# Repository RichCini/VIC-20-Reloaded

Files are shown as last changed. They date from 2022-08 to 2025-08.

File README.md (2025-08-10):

# VIC-20-Reloaded
Reimaging of the original VIC-20cr ("cost-reduced") main board in a smaller footprint based
on schmetics of the 251027-01D version as redrawn by Steve Gray. This should represent
changes through ECO 830151 as of 4/12/1983.

## Introduction
This project is a re-implementation of a VIC-20 based on the cost-reduced version from 1983.
It's built using commonly-existing TTL (all of the original types of chips used are still 
generally available) and original core chips from a VIC-20 (the CPU, VIAs, VIC, and original
mask ROMs) which were typically socketed. The memory chips (2114L and 6116), which are not
typically socketed, are still available as used or new-old-stock. 

## How is this version similar?
Since it's based on the original schematics, it's identical operationally and 99% identical
electrically (except as noted in the next section). I also tried to keep the parts placement
relationally similar to the original, recognizing that the board size is different. Parts 
designators are the same.

## How is this version different?
### Size
My main goal was to reimplement the VIC in a smaller form factor. I was able to squeeze it
{mostly} into an S-100 format (which is 10" x 5"; actual is 10.375" x 5.375") size. As such,
this board isn't a drop-in replacement. However, the spacing and placement of the side 
(power/joystick) and the rear (expansion cartridge, video, serial IEC) are
placed at the correct distances from the upper-right corner.

### Ports
Due to the smaller form factor, the cassette port was eliminated (instead opting for a 
6-pin header for an external driver) and the user port was moved to the left side. The 
orientation of the expansion connector was changed to vertical (more like the Atari 2600
which saved about 2" of board space). Using the expansion connector is limited to one
cartridge, or an expansion board that uses two pieces connected by a cable (there is
another repro here that has an example).

### Power
Electrically, I opted for a single 5V power supply (9VAC wasn't needed as there is no
cassette port), and the power switch is slightly different due to parts availability.
The main fuse holder is different, but the same 5x20mm fuse is used. Large axial
capacitor was replaced with smaller radial cap of the same value.

### Other
Since the board is autorouted to a smaller footprint, circuit paths and keepout
areas are different from the original.

## Versions
* v1.0-001: Initial prototype based on original schematic; screen artifacts
* v1.1-001: Second prototype with a rearranged chip layout; screen artifacts.
* v1.1-002: Third prototype. A transcription error was found in the original schematic.  
            Corrected. Works.
* v1.1-002E: Final version.

## Known Bugs
Current Release (1.1-002E):
* The signal flag "S01" was incorrectly used for the CPU PHI1 output. The system works
  with this improperly connected signal, but the fix is to lift pins UE10.3 and UC3.3
  and connect them with a jumper. The way the traces are routed make it hard to make a
  single-cut fix.

Prior Release (1.1-002D): 
* An error was introduced in this version as a result of rearranging the data bus lines
  lines on IC UF8 (74LS245). D4 (pin 4) and D5 (pin 5) were reversed. There is a picture
  (ECO_001) which indicates a convenient place to cut two traces and cross-wire them.
  Will be fixed in the next version.

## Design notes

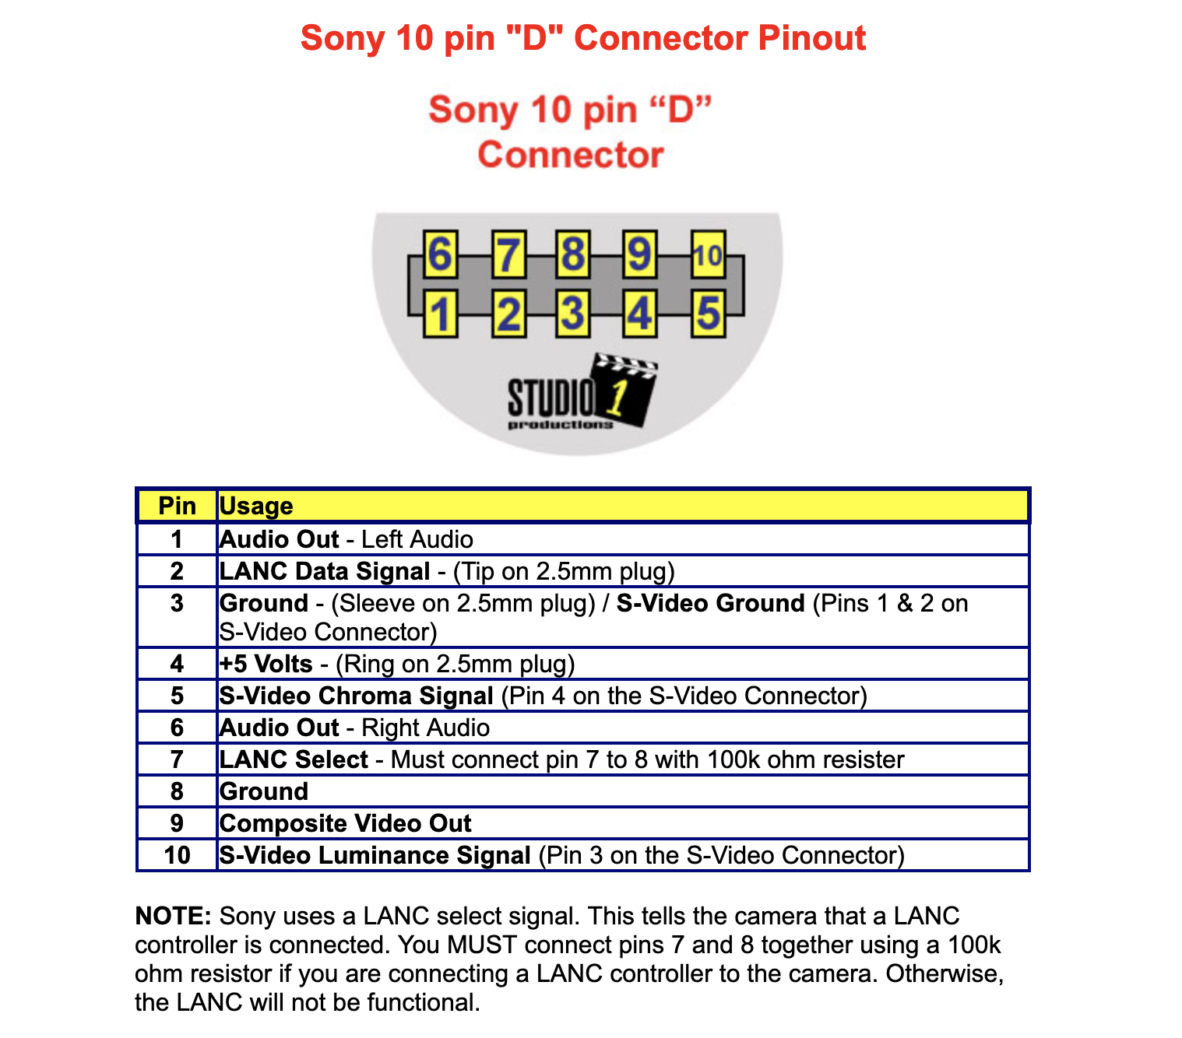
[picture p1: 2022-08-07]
sony_svideo_cable.png

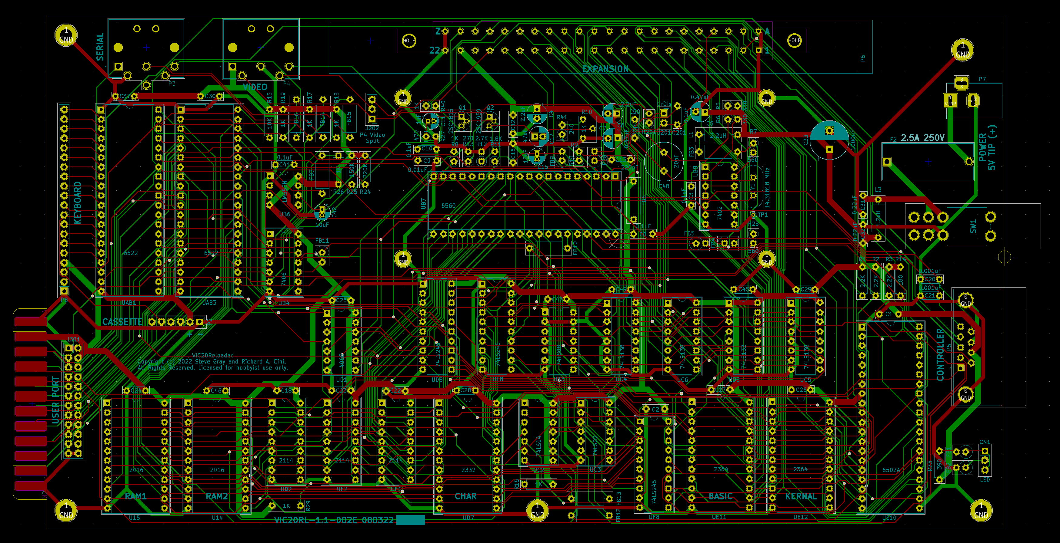
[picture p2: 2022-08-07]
Screen Shot 2022-08-06 at 4.35.58 PM.png

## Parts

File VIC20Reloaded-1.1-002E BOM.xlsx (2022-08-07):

Item | Qty | Order | Reference(s) | Value | Description | Footprint | Mouser Part Number
1 | 24 |  | C1, C2, C3, C8, C10, C12, C16, C18, C22, C23, C24, C25, C26, C27, C28, C29, C30, C37, C41, C45, C46, C47, C49, C201 | 0.1uF 50v X7R | Bypass capacitor 5mm | Capacitor_THT:C_Disc_D4.3mm_W1.9mm_P5.00mm | K104K15X7RF53H5
2 | 2 |  | C4, C6 | 2.2uF 35v | Tantalum | Capacitor_THT:CP_Radial_D5.0mm_P2.50mm | 581-TAP225M035SCS
3 | 2 |  | C5, C7 | 0.47uF 35v | Tantalum | Capacitor_THT:CP_Radial_D5.0mm_P2.50mm | 581-TAP474K035SCS
4 | 1 |  | C9 | 0.01uF | MLCC | Capacitor_THT:C_Disc_D4.3mm_W1.9mm_P5.00mm
5 | 1 |  | C11 | 1uF 50v | Electrolytic 4x1.5mm | Capacitor_THT:CP_Radial_D4.0mm_P1.50mm | UMA1H010MDD
6 | 1 |  | C13 | 220pF 50v | MLCC | Capacitor_THT:C_Disc_D4.3mm_W1.9mm_P5.00mm | FG28C0G1H221JNT06
7 | 2 |  | C15, C42 | 10uF 50v | Electrolytic 4x1.5mm | Capacitor_THT:CP_Radial_D4.0mm_P1.50mm | 50ML10MEFC5X7
8 | 1 |  | C17 | 47uF 25v | Electrolytic 4x2mm | Capacitor_THT:CP_Radial_D4.0mm_P2.00mm | ESS476M016AC2AA
9 | 2 |  | C20, C21 | 0.001uF 50v | MLCC | Capacitor_THT:C_Disc_D4.3mm_W1.9mm_P5.00mm
10 | 2 |  | C31, C32 | 0.22uF 50v | MLCC | Capacitor_THT:C_Disc_D4.3mm_W1.9mm_P5.00mm | 810-FG24X7R1H224KNT00
11 | 1 |  | C33 | 2200uF, 16v Alt | Electrolytic 10x16x5mm | Capacitor_THT:CP_Radial_D10.0mm_P5.00mm | 80-A750MW228M1CAAE10
12 | 1 |  | C48 | 20pF 100v | trimmer cap (red) 6-30pF | Capacitor_THT:C_Radial_D10.0mm_H12.5mm_P5.00mm | GKG30015
13 | 1 |  | C50 | 15pF 50v | ceramic | Capacitor_THT:C_Disc_D4.3mm_W1.9mm_P5.00mm | FG28C0G1H150JNT06
14 | 1 |  | CN1 | CONN_01X03 | 1x3 0.1" header/power LED | Connector_PinHeader_2.54mm:PinHeader_1x03_P2.54mm_Vertical
15 | 1 |  | F2 | 2.5A 5mm FB fuse |  | standard 5x20mm fuse | 530-5SF2.5-R
16 | 1 |  | F2X | 5mm fuse holder |  | Fuse holder, Keystone 4527 | 534-4527
17 | 1 |  | F2X1 | fuse holder cover |  | Fuse holder, Keystone 4527 cover | 534-4527C
18 | 7 |  | FB1, FB2, FB4, FB5, FB8, FB9, FB11 | FILTER | ferrite bead, Fair-Rite | Inductor_THT:L_Axial_L7.0mm_D3.3mm_P2.54mm_Vertical | 2743001112
19 | 9 |  | FB3, FB6, FB7, FB10, FB12, FB13, FB14, FB15, FB16 | FILTER | ferrite bead, Fair-Rite | Inductor_THT:L_Axial_L7.0mm_D3.3mm_P10.16mm_Horizontal | 2743001112
20 | 1 |  | J201 | Jumper 1x3 |  | video configuration jumper
21 | 1 |  | J202 | Jumper 1x2 |  | video configuration jumper
22 | 1 |  | L1 | 2.2uH | inductor, Bourns, 630mA | Inductor_THT:L_Axial_L7.0mm_D3.3mm_P10.16mm_Horizontal | 78F2R2K-RC
23 | 1 |  | L3 | 1.2uH | inductor, TDK, 4.25A | Inductor_THT:L_Axial_L7.0mm_D3.3mm_P10.16mm_Horizontal | B82144F2122K000
24 | 1 |  | P1 | CONN_02X12 | 2x12 0.1" header USERP | Connector_PinHeader_2.54mm:PinHeader_2x12_P2.54mm_Vertical
25 | 1 |  | P2 | Header, 1x6 | 1x6 0.1" header CASS | Connector_PinHeader_2.54mm:PinHeader_1x06_P2.54mm_Vertical
26 | 1 |  | P3 | DIN6 | DIN6 Serial IEC |  | SDS-60J
27 | 1 |  | P4 | DIN5 | DIN5 Video |  | 490-SDS-50J
28 | 1 |  | P5 | DE9M | DE9M/joystick | Connector_Dsub:DSUB-9_Male_Horizontal_P2.77x2.84mm_EdgePinOffset7.70mm_Housed_MountingHolesOffset9.12mm | ID09P33E4GX00LF
29 | 1 |  | P6 | EXPANSION | 2x22 card connector | EDAC. Can be vertical or R/A depending on need | 307-044-524-202
30 | 1 |  | P6-Alt | EXPANSION | 2x22 R/A card connector | EDAC. Can be vertical or R/A depending on need | 307-044-558-201
31 | 1 |  | P7 | POWER TIP+ | barrel jack | Connector_BarrelJack:BarrelJack_Horizontal | PJ-002AH
32 | 1 |  | P8 | CONN_01X20 | 1x20 0.1" header KEYB | Connector_PinHeader_2.54mm:PinHeader_1x20_P2.54mm_Vertical
33 | 1 |  | Q1 | 2SC1815 | transistor | Can substitute 2N2222 | N/A
34 | 1 |  | Q2 | 2SC1959 | transistor | Can substitute 2N2222 | N/A
35 | 3 |  | R1, R2, R3 | 2.2KQ | resistor, 1/4w
36 | 2 |  | R5, R6 | 330Q | resistor, 1/4w
37 | 2 |  | R7, R28 | 560Q | resistor, 1/4w
38 | 1 |  | R9 | 510Q | resistor, 1/4w
39 | 1 |  | R10 | 1.0K vertical POT | trimmer, vertical Bourns 3266W |  | 652-3266W-1-102LF
40 | 1 |  | R11 | 1.8KQ | resistor, 1/4w
41 | 1 |  | R12 | 2.7KQ | resistor, 1/4w
42 | 1 |  | R13 | 270Q | resistor, 1/4w
43 | 1 |  | R14 | 180Q | resistor, 1/4w
44 | 6 |  | R15, R17, R18, R19, R26, R29 | 1.0KQ | resistor, 1/4w
45 | 2 |  | R8, R40 | 1.0KQ | resistor, 1/4w
46 | 1 |  | R16 | 10.0KQ | resistor, 1/4w
47 | 1 |  | R23 | 390Q | resistor, 1/4w | resistor for LED power indicator; may need to adjust based on LED
48 | 1 |  | R24 | 220KQ | resistor, 1/4w
49 | 1 |  | R25 | 150KQ | resistor, 1/4w
50 | 1 |  | R27 | 470Q | resistor, 1/4w
51 | 1 |  | R41 | 240Q | resistor, 1/4w
52 | 1 |  | R201 | 75Q | resistor, 1/4w | used for S-video modification
53 | 1 |  | SW1 | Switch, DPDT vertical | power | Mouser-Samec:M2022TXW41DA | 633-M2022TXW41-DA
54 | 1 |  | U13 | 74LS08 | Quad 2-in AND, OC |  | SN74LS08
55 | 2 |  | U14, U15 | 2016/6116 SRAM | RAM |  | N/A
56 | 2 |  | UAB1, UAB3 | R6522 VIA | VIA |  | N/A
57 | 1 |  | UB4 | 74LS06 | Hex inverter/buffer OC |  | SN74LS06
58 | 1 |  | UB6 | LM555N | timer |  | LM555CN
59 | 1 |  | UB7 | 6560 VIC-I | video |  | N/A
60 | 1 |  | UB9 | 7402 | Quad 2-in positive NOR |  | eBay-note it's original logic family
61 | 1 |  | UC2 | 74LS04 | Hex inverter |  | SN74LS04
62 | 1 |  | UC3 | 74LS02 | Quad 2-in positive NOR |  | SN74LS02
63 | 3 |  | UC4, UC5, UC6 | 74LS138 | 3-8 decoder/demux |  | SN74LS138
64 | 1 |  | UD1 | CD4066 | quad switch |  | CD4066BE
65 | 3 |  | UD2, UE1, UE2 | 2114AL-3 | 1kx4 SRAM |  | N/A
66 | 1 |  | UD7 | 2332 mask ROM | character ROM |  | N/A
67 | 3 |  | UD8, UE8, UF8 | 74LS245 | Octal bus transciever, tri-state |  | SN74LS245
68 | 1 |  | UD9 | 74LS133 | 13-input NAND |  | SN74LS133
69 | 1 |  | UE10 | 6502A | CPU |  | N/A
70 | 2 |  | UE11, UE12 | 2364 mask ROM | BASIC/KERNAL |  | N/A
71 | 1 |  | Y1 | 14.31818 MHz XTAL | must be series capacitance | Crystal:Crystal_HC49-U_Vertical | 774-MP143 | CTX088
72 | 1 |  |  | DIP8 | dual-wipe socket, crimp pin |  | 4808-3004-CP
73 | 6 |  |  | DIP14 | dual-wipe socket, crimp pin |  | 4814-3004-CP
74 | 4 |  |  | DIP16 | dual-wipe socket, crimp pin |  | 4816-3004-CP
75 | 3 |  |  | DIP18 | dual-wipe socket, crimp pin |  | 517-4818-3004-CP
76 | 3 |  |  | DIP20 | dual-wipe socket, crimp pin |  | 4820-3004-CP
77 | 5 |  |  | DIP24 | dual-wipe socket, crimp pin |  | 517-4824-6004-CP
78 | 4 |  |  | DIP40 | dual-wipe socket, crimp pin |  | 517-4840-6004-CP
 |  |  | P8F | 1x20 MTA100 | keyboard |  | 571-5-640440-0

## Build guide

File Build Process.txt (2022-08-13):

VIC20cr Reloaded Build Process
2022-08-13

In general, I build boards by component height rather than function. The former allows
for an easier bench build, while the latter enables testing by functional area of the
board. Each has its relative benefits which depend on the builder's confidence in 
building complex boards. I would note that some components are relatively expensive
(the expansion connector, the power switch, and the DE9M, for example) so I leave those
out until I confirm the board works.

Component-Oriented Build
========================
 1.	Axial components:
	Resistors: R1-3, R14-19, R23, R29
	Ferrites: FB3, FB6, FB10, FB12-16
	Inductors: L1
	
 2.	DIP Sockets. If the builder is using crimp-pin style sockets rather than the straight
	or machine pin, I recommend soldering them such that the iron rests on the knee
 	of the crimp and solder is applied in and around the vacant area under the pin
 	opposite where the iron is resting. That way, the solder fills the entire area.

 3.	Radial components:
	Capacitors: C8, C11, C13, C20-21, C31-32; all bypass caps, C48
	Inductors: L3

 4.	Axial (folded) components:
	Resistors: R5-8, R11-13, R27-28, R40-41
	Ferrites: FB1,2,4,5,8,9,11
	
 5.	Transistors

 6.	Other capacitors: C4,6,7,15,17,42

 7.	Crystal and ground wire

 8.	Headers P2, P8, CN1, J301

 9.	Capacitor C33

10.	Switch SW1

11.	Power jack P7

12. 	Fuse F7

13.	Joystick P5

14. 	Serial IEC/Video P3,P4

15.	Expansion Connector P6. Use two small 4-40 screws to secure to the board to 
	provide some strain relief.

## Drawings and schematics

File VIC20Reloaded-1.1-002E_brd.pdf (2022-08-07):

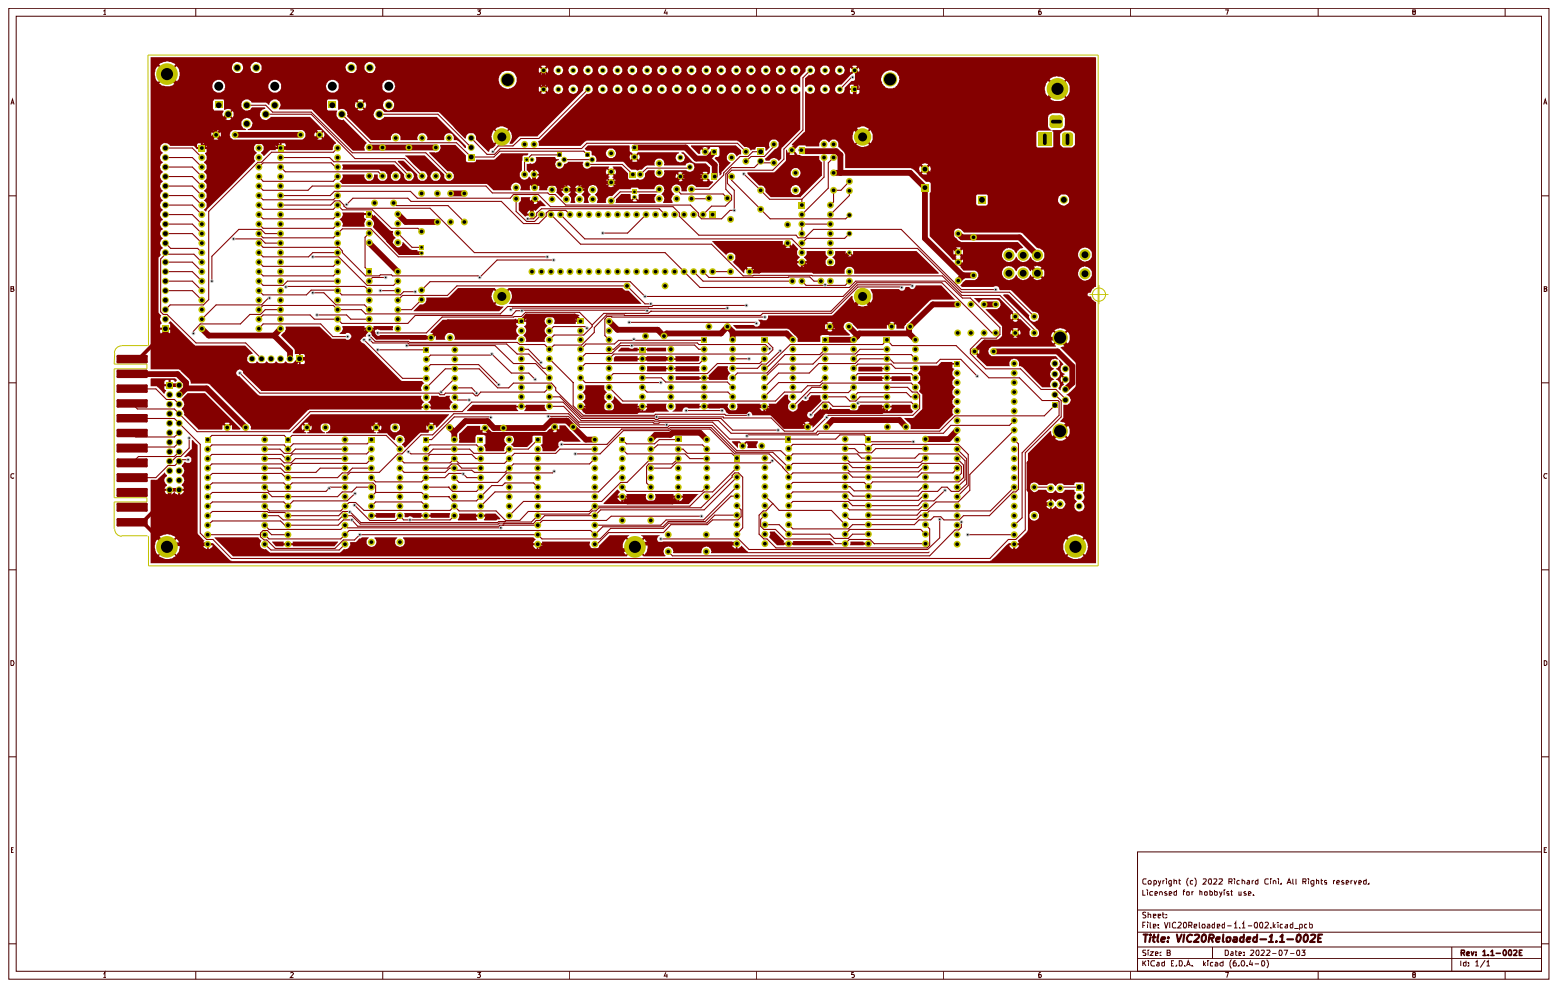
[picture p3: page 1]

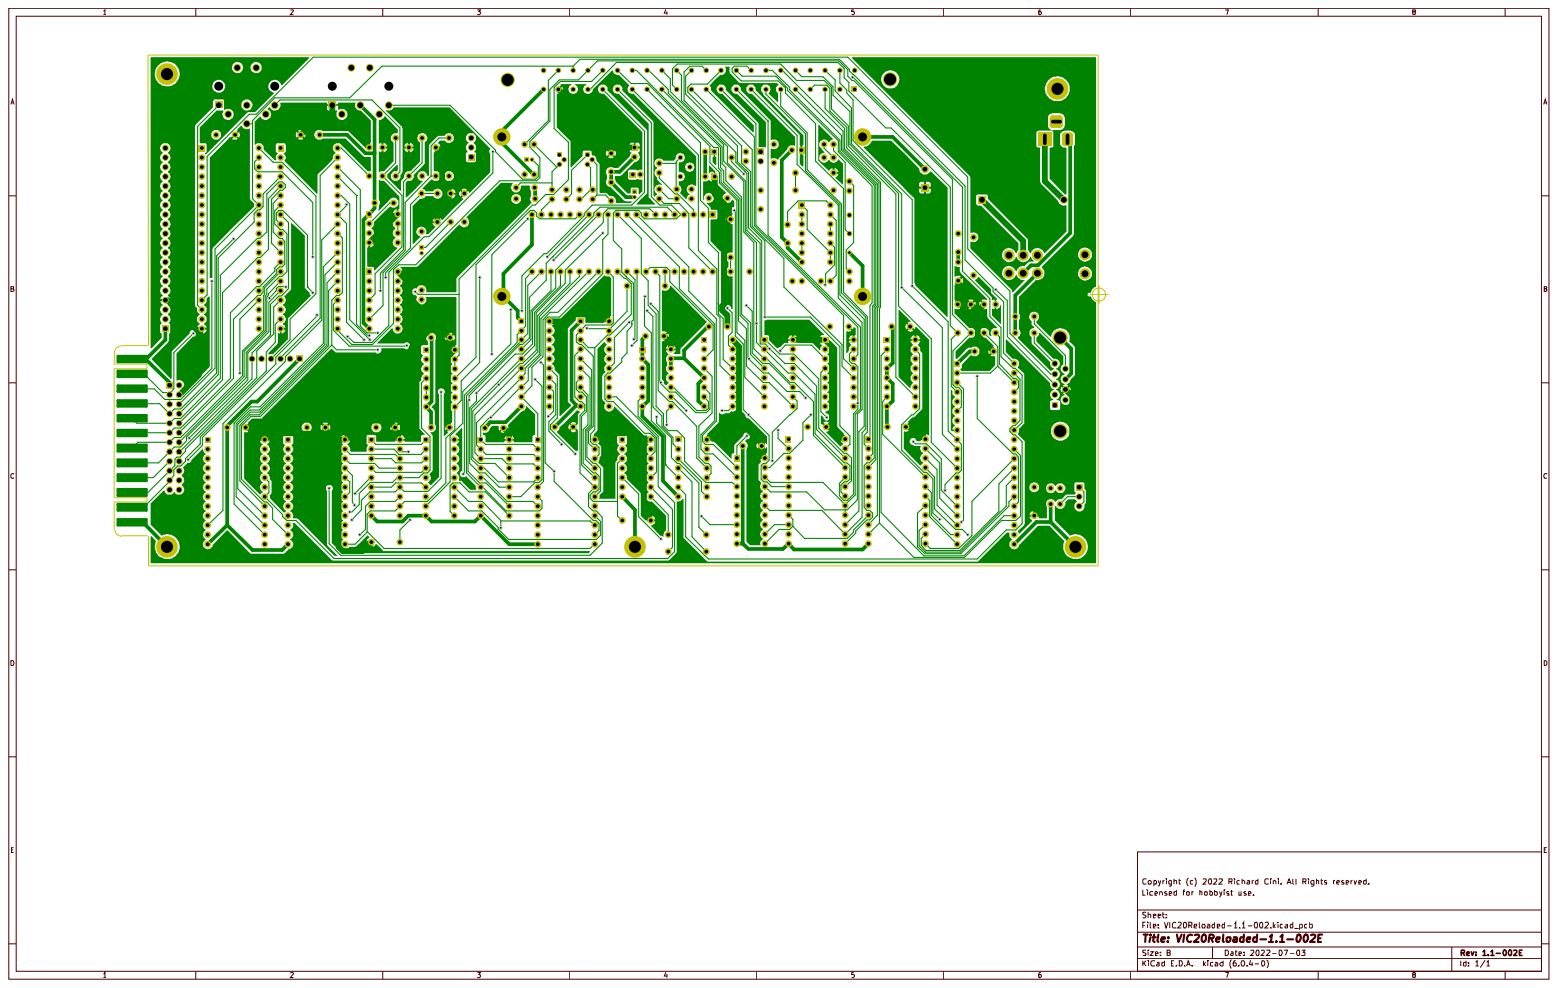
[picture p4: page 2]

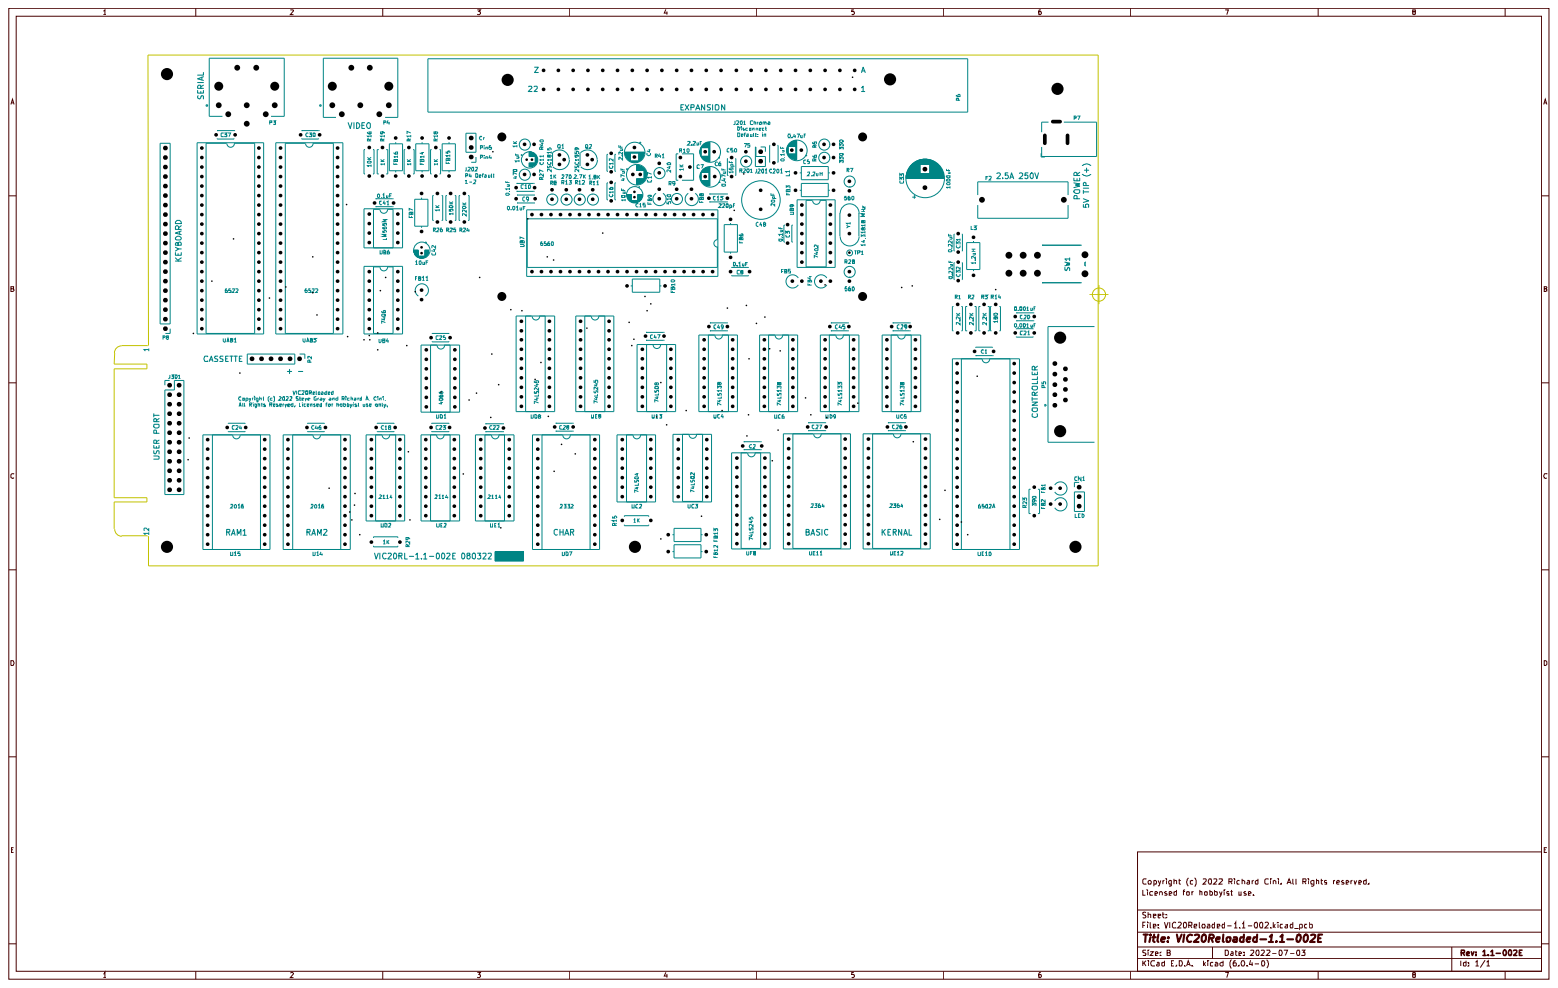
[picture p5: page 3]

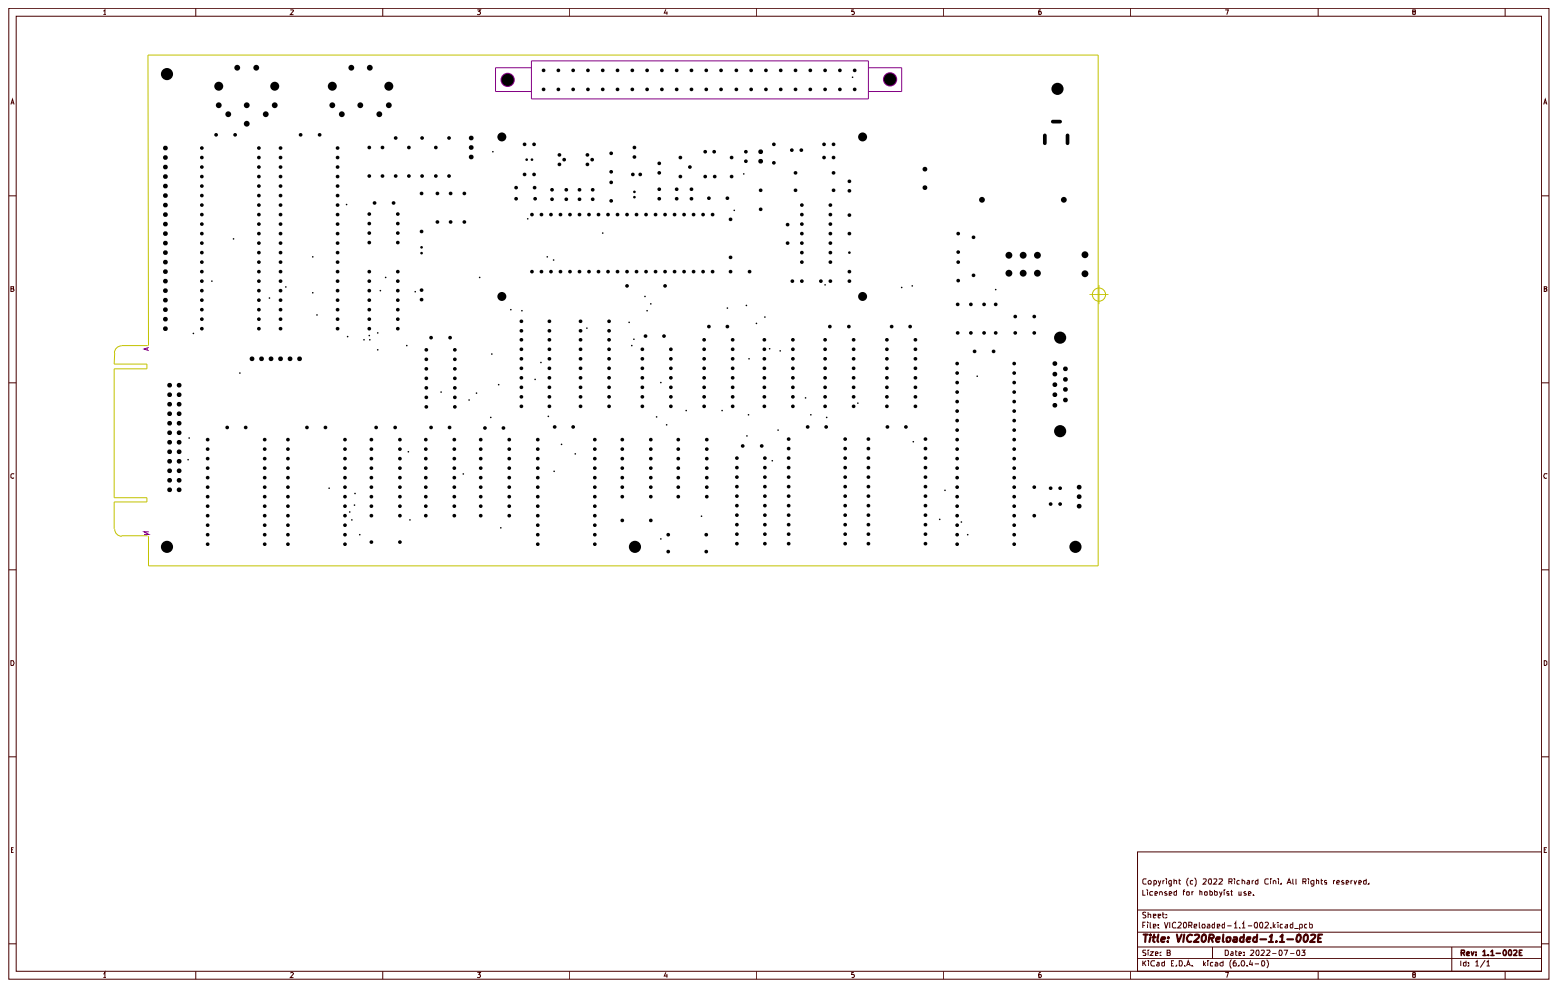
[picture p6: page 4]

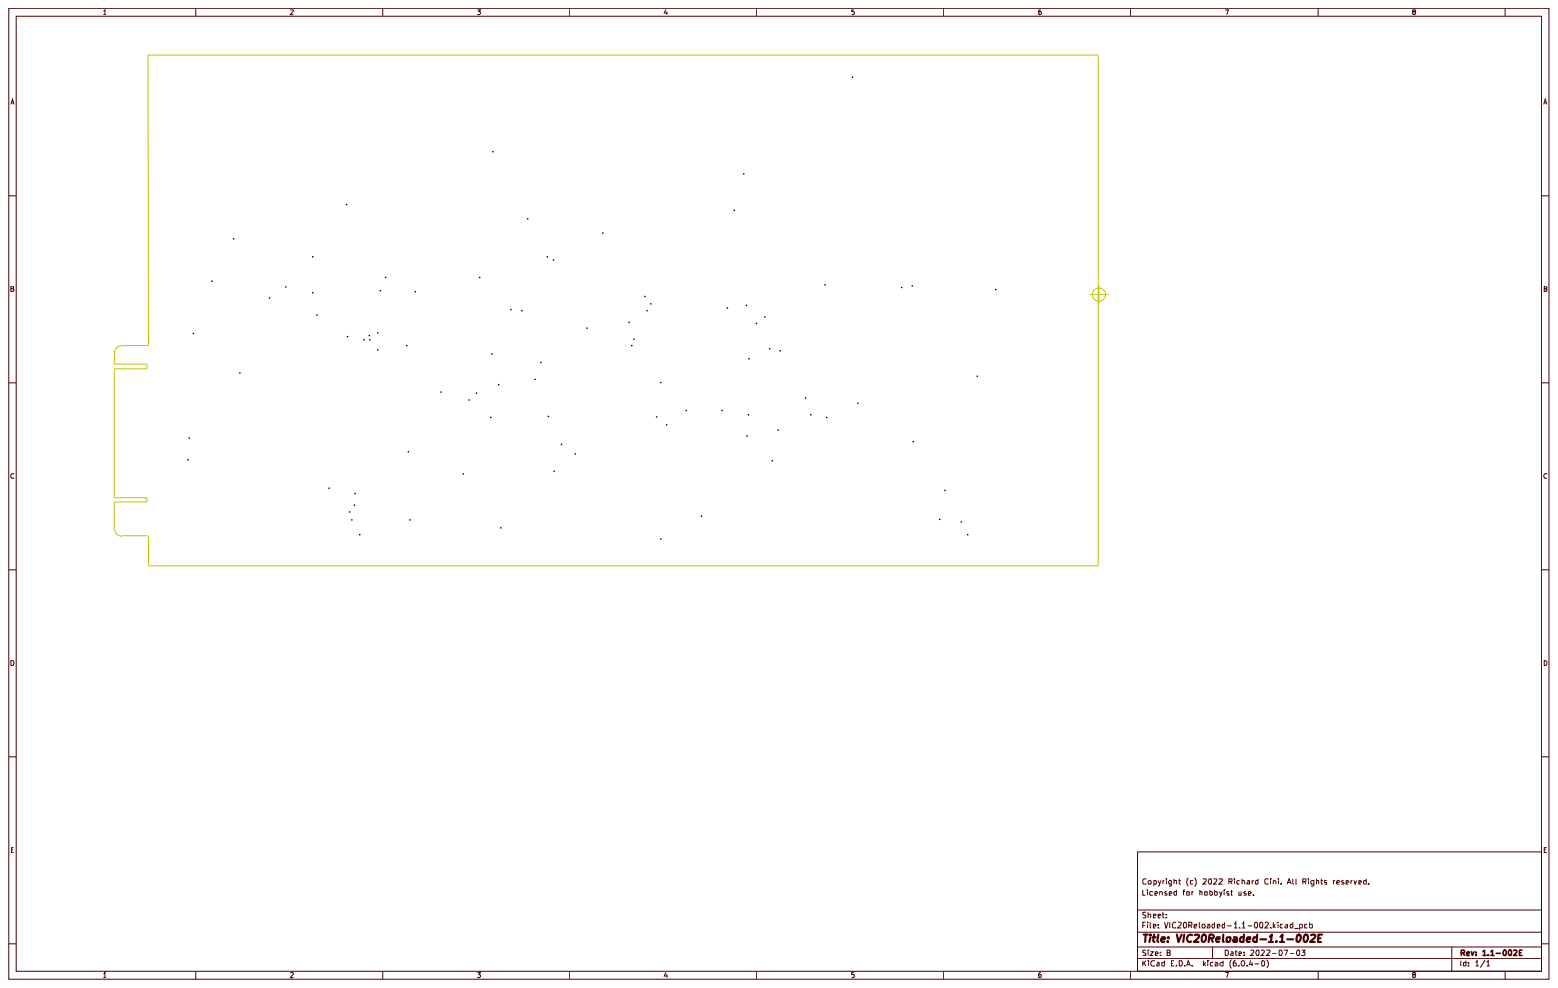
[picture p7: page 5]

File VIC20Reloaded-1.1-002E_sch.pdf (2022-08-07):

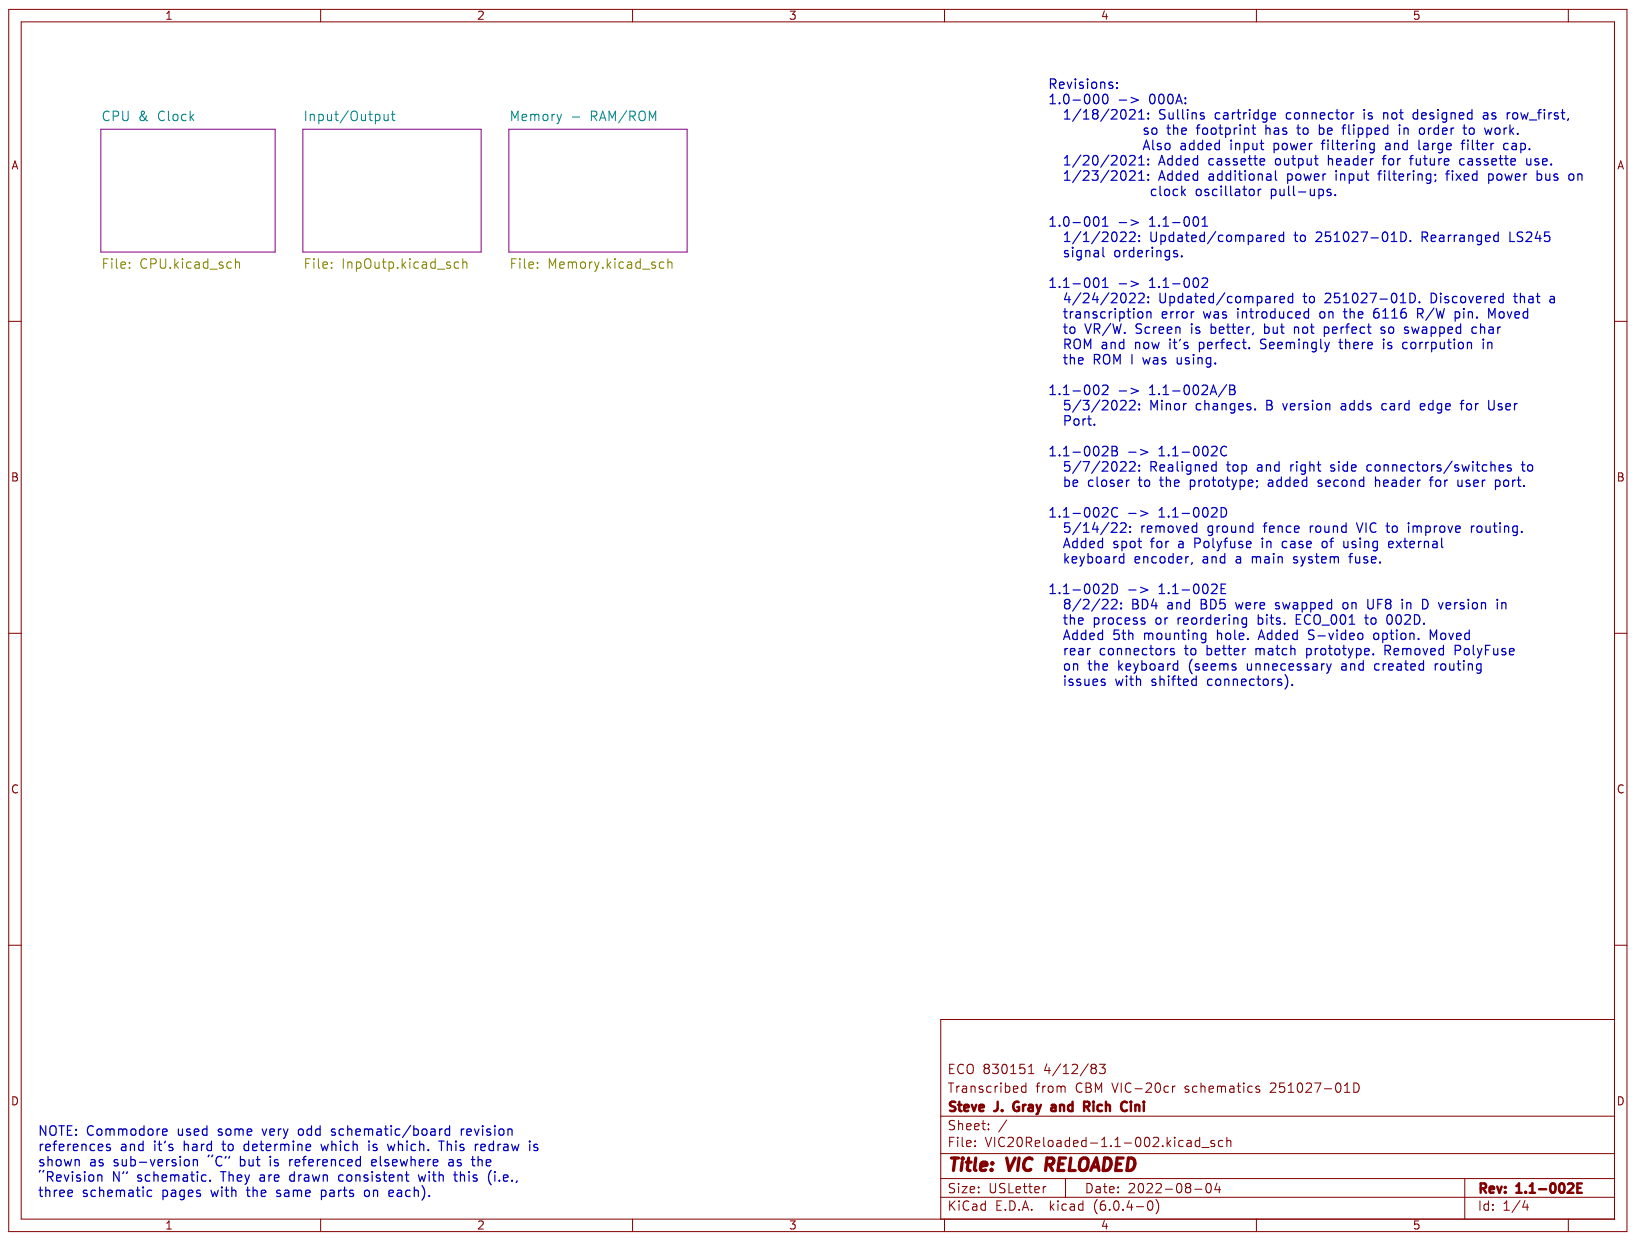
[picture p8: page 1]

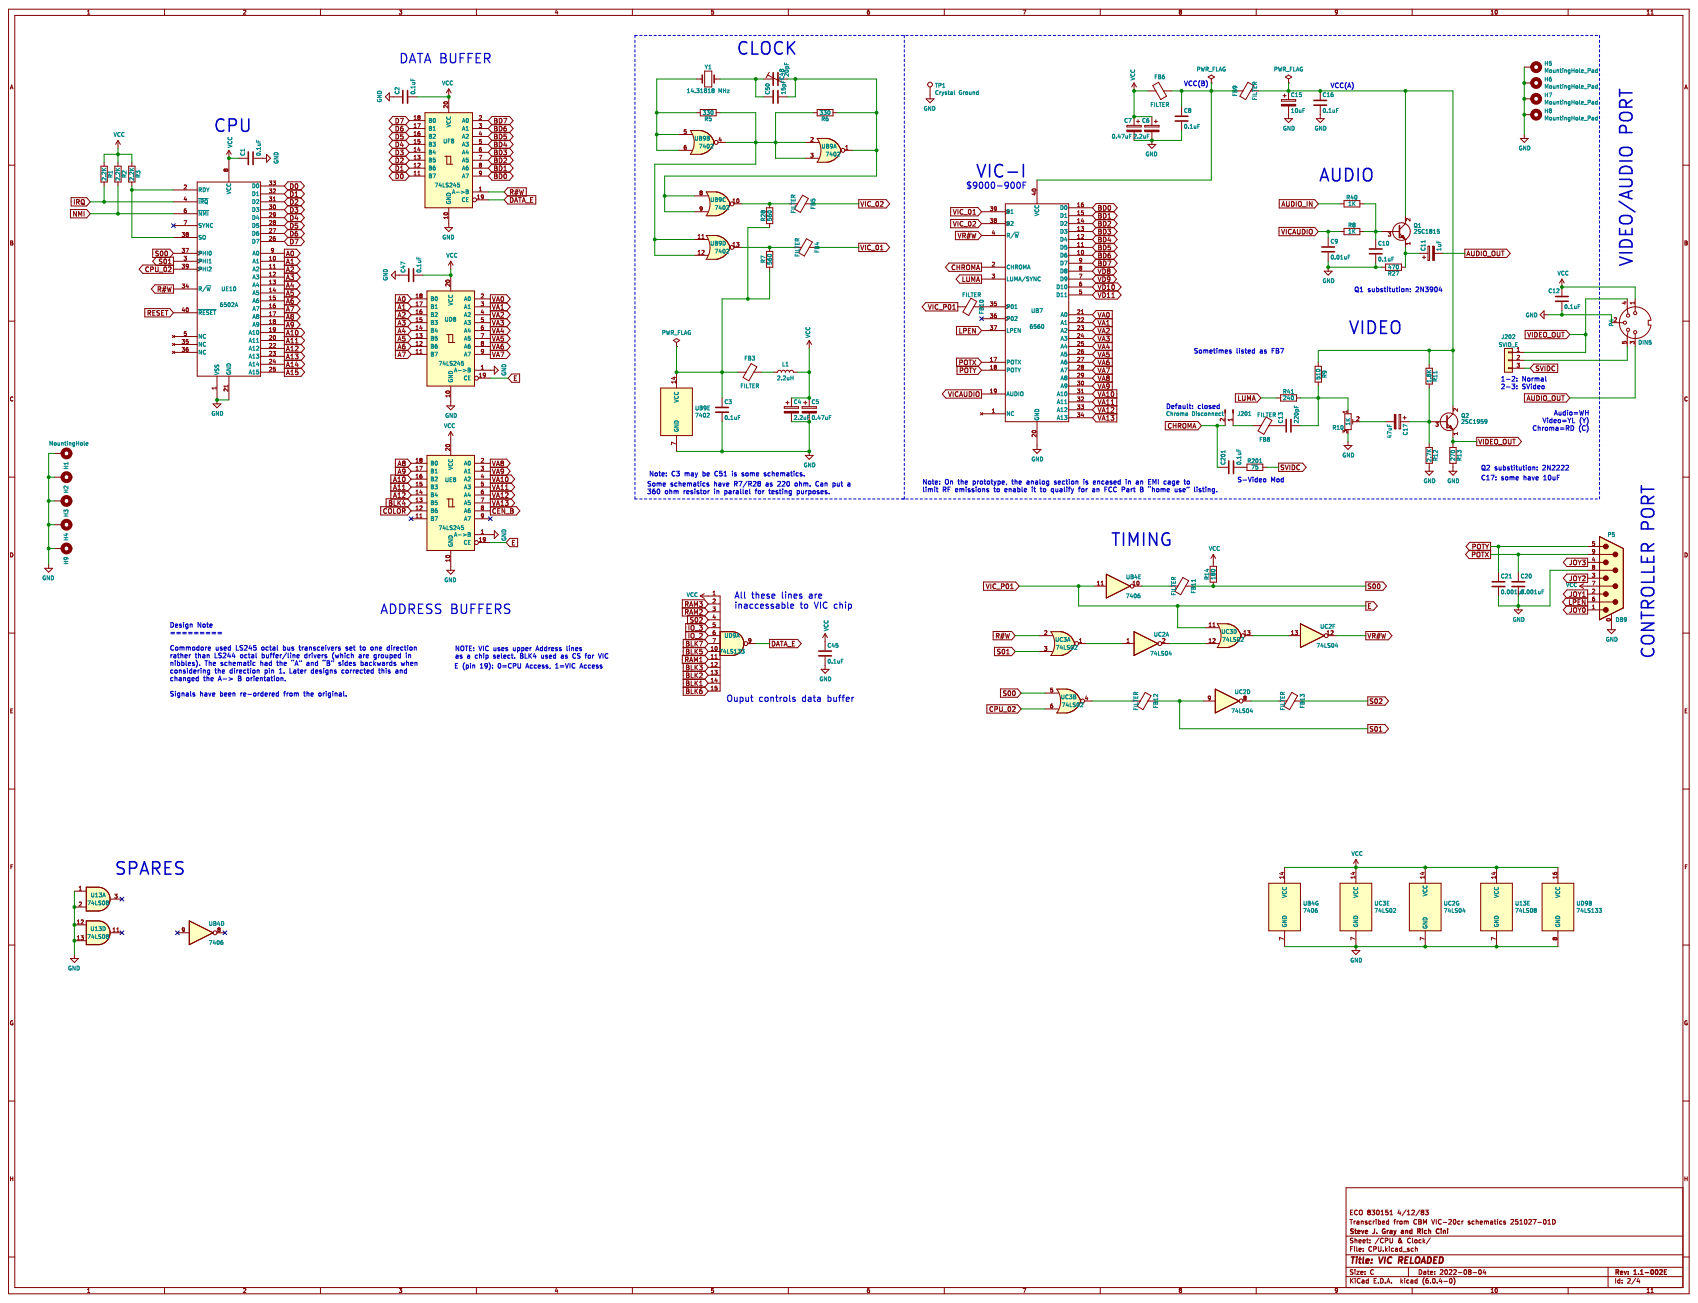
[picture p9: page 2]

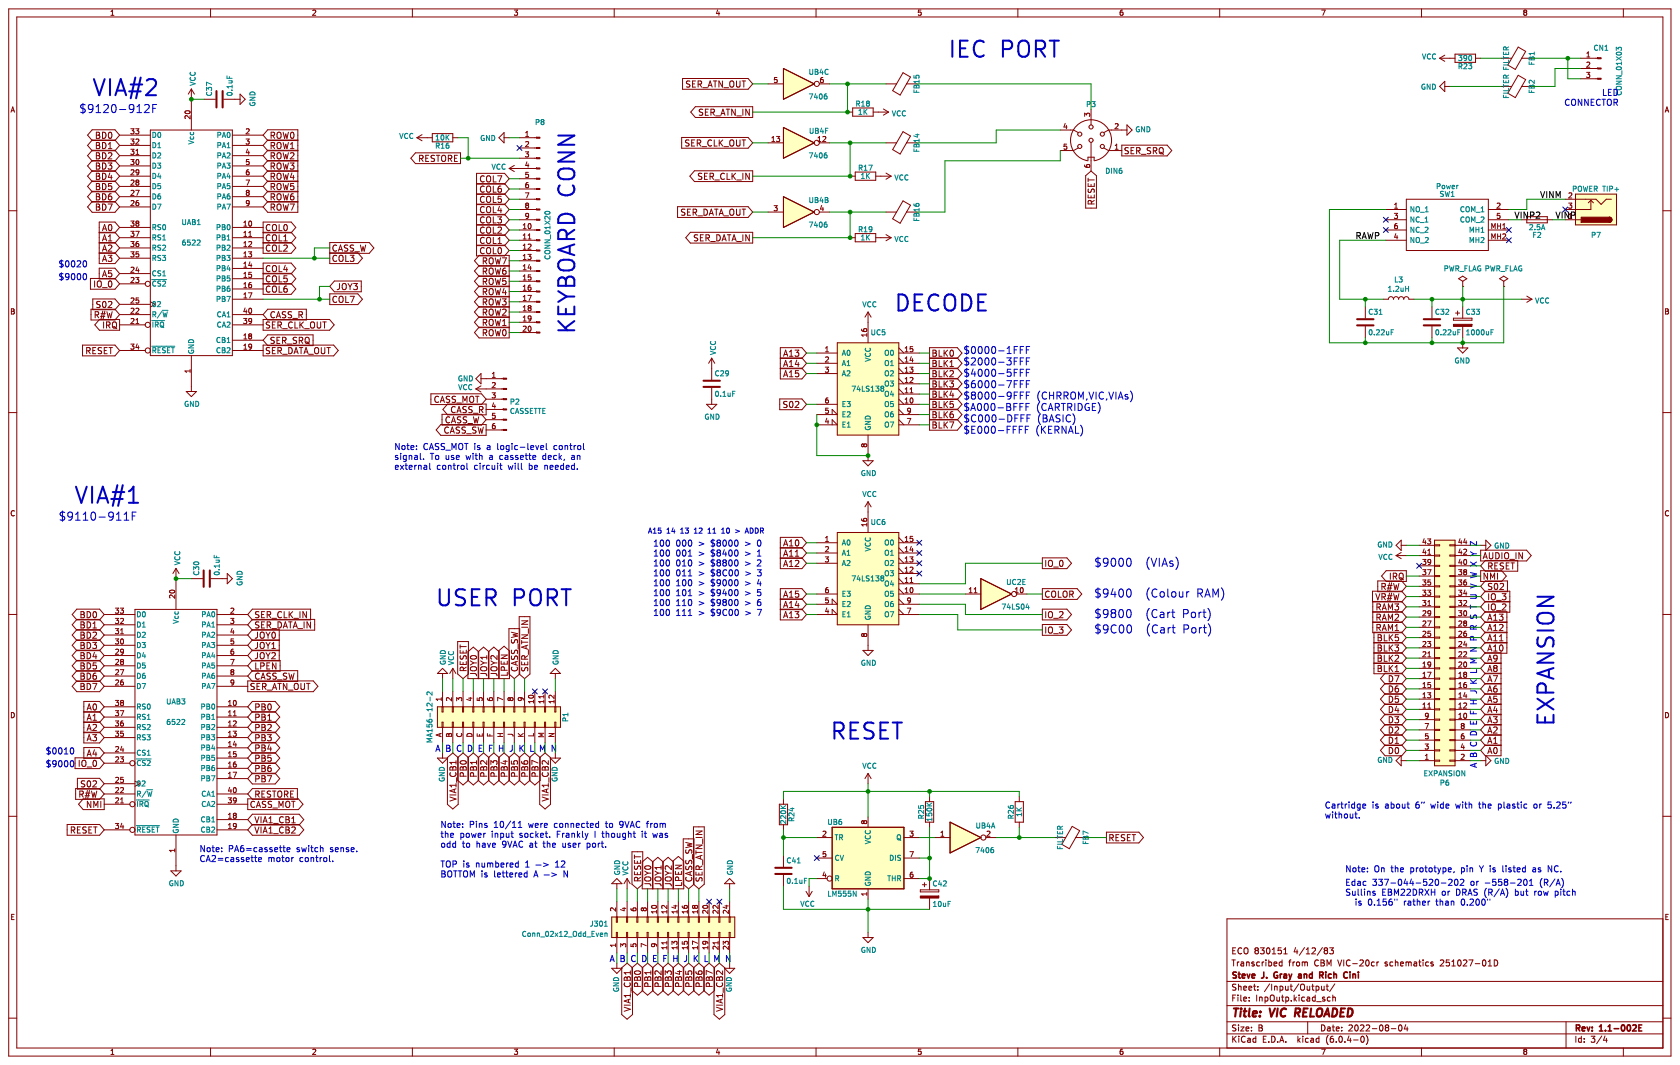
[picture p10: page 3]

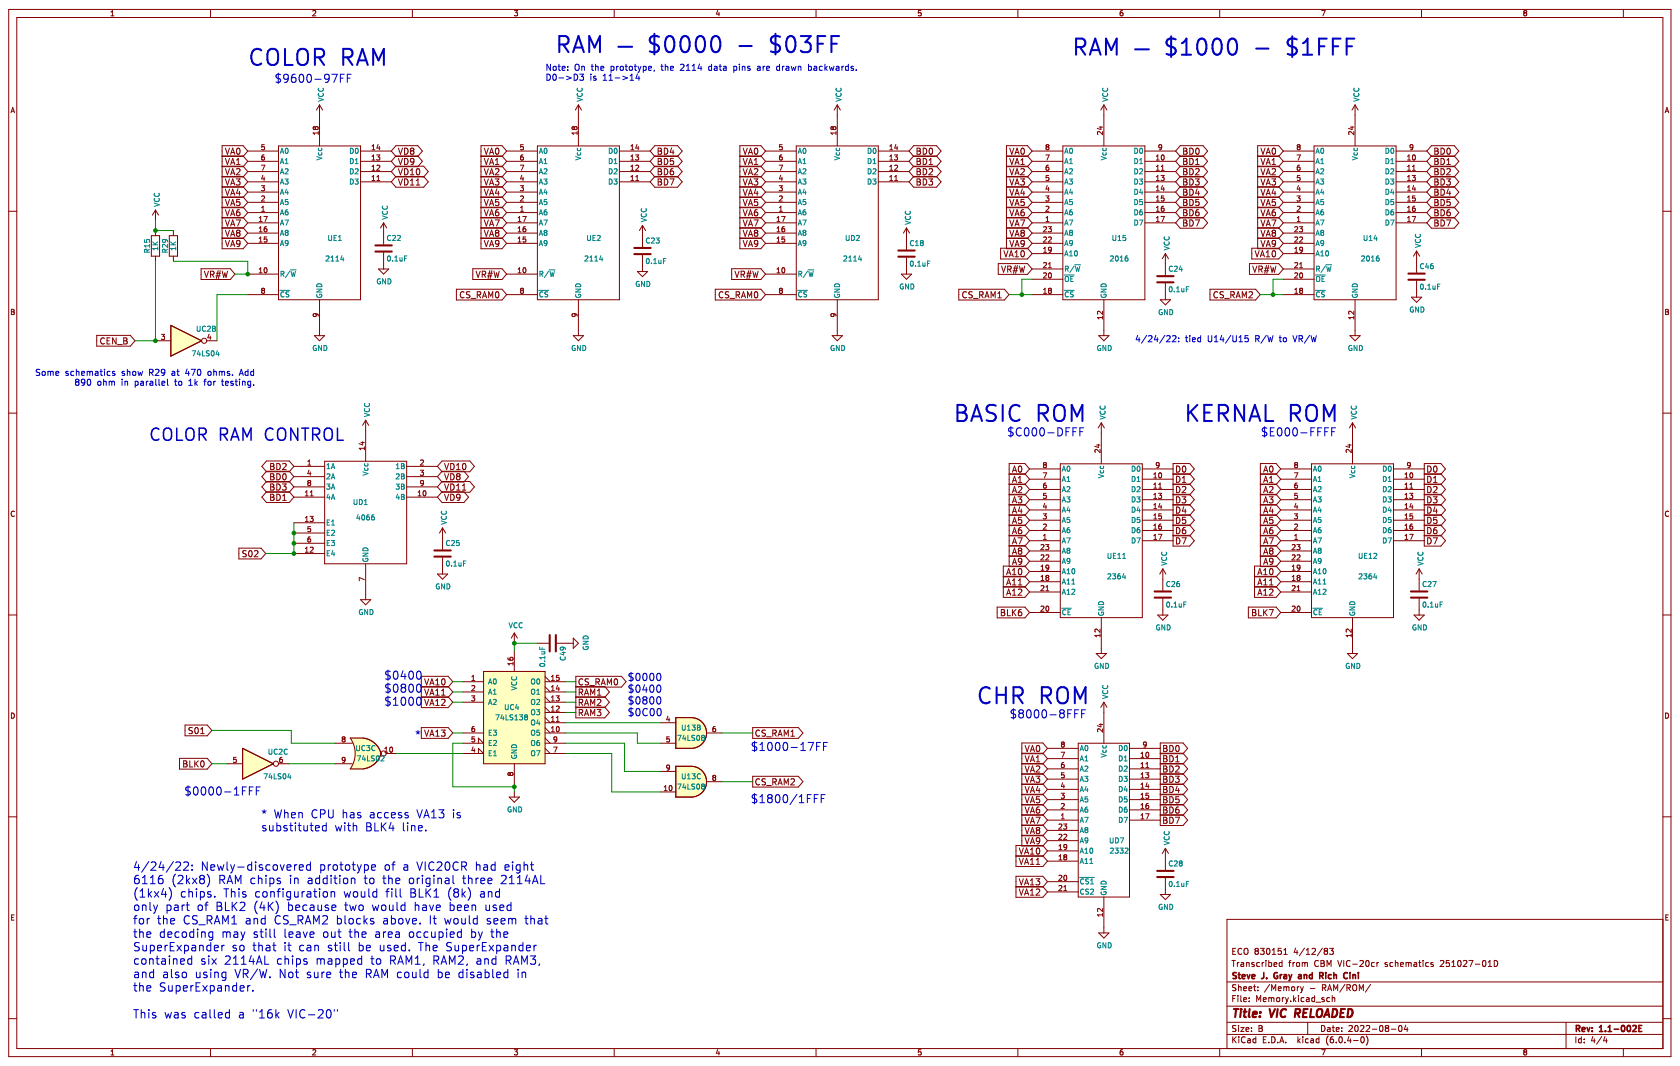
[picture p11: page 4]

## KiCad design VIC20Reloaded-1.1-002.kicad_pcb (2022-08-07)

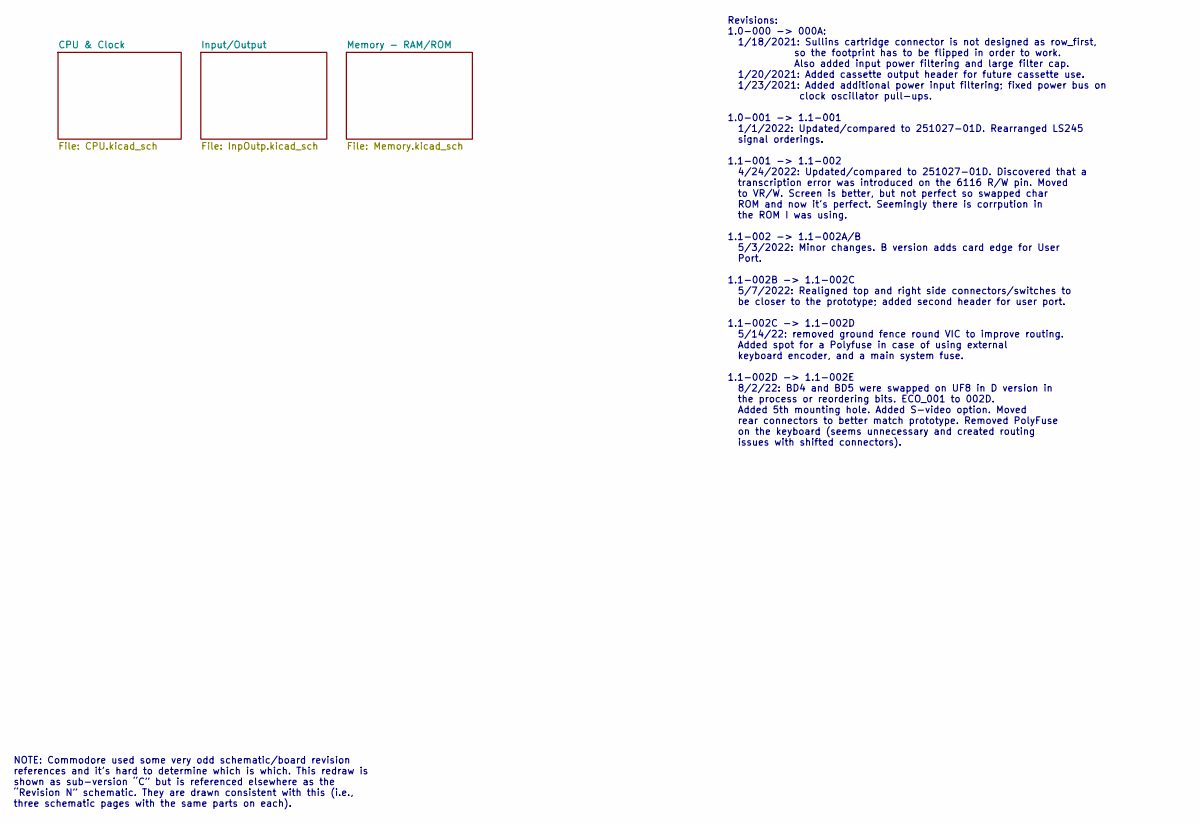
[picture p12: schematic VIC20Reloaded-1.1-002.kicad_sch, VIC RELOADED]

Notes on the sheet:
NOTE: Commodore used some very odd schematic/board revision references and it’s hard to determine which is which. This redraw is shown as sub-version “C” but is referenced elsewhere as the “Revision N” schematic. They are drawn consistent with this (i.e., three schematic pages with the same parts o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
Revisions: 1.0-000 -> 000A: 1/18/2021: Sullins cartridge connector is not designed as row_first, so the footprint has to be flipped in order to work. Also added input power filtering and large filter cap. 1/20/2021: Added cassette output header for future cassette use. 1/23/2021: Added additional p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

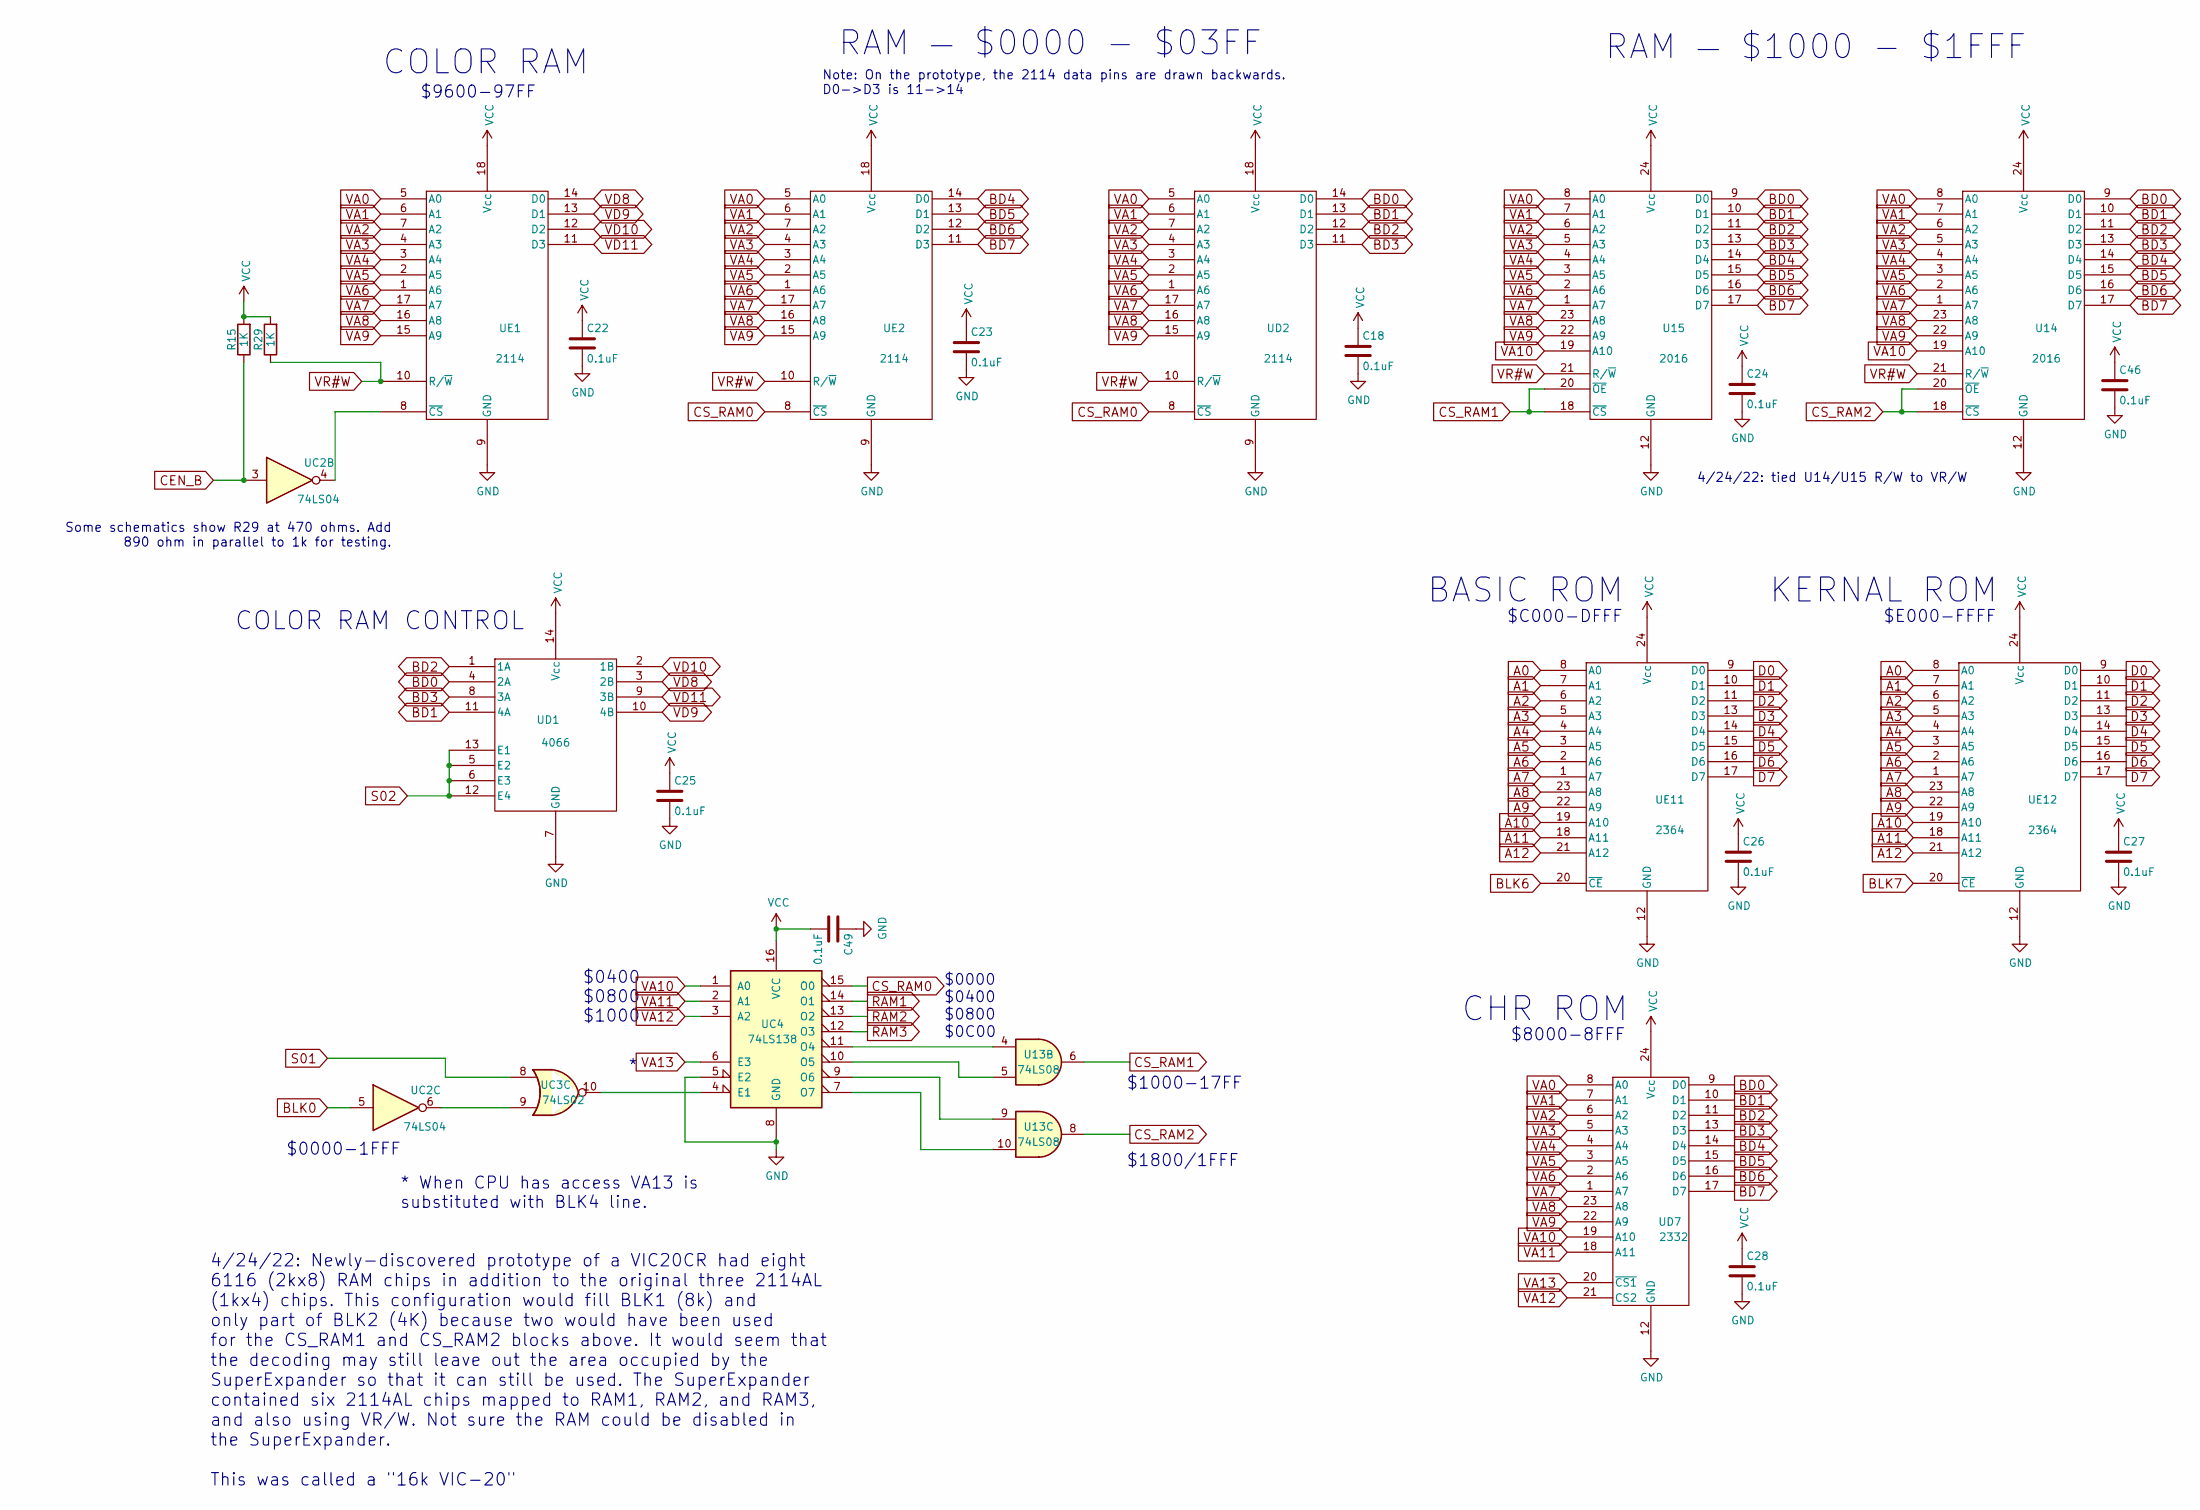
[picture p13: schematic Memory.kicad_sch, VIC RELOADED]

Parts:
C18, C22, C23, C24, C25, C26, C27, C28, C46, C49: 0.1uF; C_Disc_D4.3mm_W1.9mm_P5.00mm
R15, R29: 1K; R_Axial_DIN0207_L6.3mm_D2.5mm_P7.62mm_Horizontal
U13: 74LS08; DIP-14_W7.62mm_Socket
U14, U15: 2016; DIP-24_W15.24mm_Socket
UC2: 74LS04; DIP-14_W7.62mm_Socket
UC3: 74LS02; DIP-14_W7.62mm_Socket
UC4: 74LS138; DIP-16_W7.62mm_Socket
UD1: 4066; DIP-14_W7.62mm_Socket
UD2: 2114; DIP-18_W7.62mm_Socket
UD7: 2332; DIP-24_W15.24mm_Socket
UE1, UE2: 2114; DIP-18_W7.62mm_Socket
UE11, UE12: 2364; DIP-24_W15.24mm_Socket

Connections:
A0: UE11.8 (A0), UE12.8 (A0); also elsewhere on the board
A1: UE11.7 (A1), UE12.7 (A1); also elsewhere on the board
A2: UE11.6 (A2), UE12.6 (A2); also elsewhere on the board
A3: UE11.5 (A3), UE12.5 (A3); also elsewhere on the board
A4: UE11.4 (A4), UE12.4 (A4); also elsewhere on the board
A5: UE11.3 (A5), UE12.3 (A5); also elsewhere on the board
A6: UE11.2 (A6), UE12.2 (A6); also elsewhere on the board
A7: UE11.1 (A7), UE12.1 (A7); also elsewhere on the board
A8: UE11.23 (A8), UE12.23 (A8); also elsewhere on the board
A9: UE11.22 (A9), UE12.22 (A9); also elsewhere on the board
A10: UE11.19 (A10), UE12.19 (A10); also elsewhere on the board
A11: UE11.18 (A11), UE12.18 (A11); also elsewhere on the board
A12: UE11.21 (A12), UE12.21 (A12); also elsewhere on the board
BD0: U14.9 (D0), U15.9 (D0), UD1.4 (2A), UD2.14 (D0), UD7.9 (D0); also elsewhere on the board
BD1: U14.10 (D1), U15.10 (D1), UD1.11 (4A), UD2.13 (D1), UD7.10 (D1); also elsewhere on the board
BD2: U14.11 (D2), U15.11 (D2), UD1.1 (1A), UD2.12 (D2), UD7.11 (D2); also elsewhere on the board
BD3: U14.13 (D3), U15.13 (D3), UD1.8 (3A), UD2.11 (D3), UD7.13 (D3); also elsewhere on the board
BD4: U14.14 (D4), U15.14 (D4), UD7.14 (D4), UE2.14 (D0); also elsewhere on the board
BD5: U14.15 (D5), U15.15 (D5), UD7.15 (D5), UE2.13 (D1); also elsewhere on the board
BD6: U14.16 (D6), U15.16 (D6), UD7.16 (D6), UE2.12 (D2); also elsewhere on the board
BD7: U14.17 (D7), U15.17 (D7), UD7.17 (D7), UE2.11 (D3); also elsewhere on the board
BLK0: UC2.5; also elsewhere on the board
BLK6: UE11.20 (~CE); also elsewhere on the board
BLK7: UE12.20 (~CE); also elsewhere on the board
CEN_B: R15.1, UC2.3; also elsewhere on the board
CS_RAM0: UC4.15 (O0), UD2.8 (~CS), UE2.8 (~CS)
CS_RAM1: U13.6, U15.18 (~CS), U15.20 (~OE)
CS_RAM2: U13.8, U14.18 (~CS), U14.20 (~OE)
D0: UE11.9 (D0), UE12.9 (D0); also elsewhere on the board
D1: UE11.10 (D1), UE12.10 (D1); also elsewhere on the board
D2: UE11.11 (D2), UE12.11 (D2); also elsewhere on the board
D3: UE11.13 (D3), UE12.13 (D3); also elsewhere on the board
D4: UE11.14 (D4), UE12.14 (D4); also elsewhere on the board
D5: UE11.15 (D5), UE12.15 (D5); also elsewhere on the board
D6: UE11.16 (D6), UE12.16 (D6); also elsewhere on the board
D7: UE11.17 (D7), UE12.17 (D7); also elsewhere on the board
GND: C18.2, C22.2, C23.2, C24.2, C25.2, C26.2, C27.2, C28.2, C46.2, C49.1, U14.12 (GND), U15.12 (GND), UC4.5 (E2), UC4.8 (GND), UD1.7 (GND), UD2.9 (GND), UD7.12 (GND), UE1.9 (GND), UE2.9 (GND), UE11.12 (GND), UE12.12 (GND); also elsewhere on the board
unnamed: U13.4, UC4.11 (O4)
unnamed: U13.5, UC4.10 (O5)
unnamed: U13.9, UC4.9 (O6)
unnamed: U13.10, UC4.7 (O7)
unnamed: UC2.4, UE1.8 (~CS)
unnamed: UC2.6, UC3.9
unnamed: UC3.10, UC4.4 (E1)
RAM1: UC4.14 (O1); also elsewhere on the board
RAM2: UC4.13 (O2); also elsewhere on the board
RAM3: UC4.12 (O3); also elsewhere on the board
S01: UC3.8; also elsewhere on the board
S02: UD1.5 (E2), UD1.6 (E3), UD1.12 (E4), UD1.13 (E1); also elsewhere on the board
VA0: U14.8 (A0), U15.8 (A0), UD2.5 (A0), UD7.8 (A0), UE1.5 (A0), UE2.5 (A0); also elsewhere on the board
VA1: U14.7 (A1), U15.7 (A1), UD2.6 (A1), UD7.7 (A1), UE1.6 (A1), UE2.6 (A1); also elsewhere on the board
VA2: U14.6 (A2), U15.6 (A2), UD2.7 (A2), UD7.6 (A2), UE1.7 (A2), UE2.7 (A2); also elsewhere on the board
VA3: U14.5 (A3), U15.5 (A3), UD2.4 (A3), UD7.5 (A3), UE1.4 (A3), UE2.4 (A3); also elsewhere on the board
VA4: U14.4 (A4), U15.4 (A4), UD2.3 (A4), UD7.4 (A4), UE1.3 (A4), UE2.3 (A4); also elsewhere on the board
VA5: U14.3 (A5), U15.3 (A5), UD2.2 (A5), UD7.3 (A5), UE1.2 (A5), UE2.2 (A5); also elsewhere on the board
VA6: U14.2 (A6), U15.2 (A6), UD2.1 (A6), UD7.2 (A6), UE1.1 (A6), UE2.1 (A6); also elsewhere on the board
VA7: U14.1 (A7), U15.1 (A7), UD2.17 (A7), UD7.1 (A7), UE1.17 (A7), UE2.17 (A7); also elsewhere on the board
VA8: U14.23 (A8), U15.23 (A8), UD2.16 (A8), UD7.23 (A8), UE1.16 (A8), UE2.16 (A8); also elsewhere on the board
VA9: U14.22 (A9), U15.22 (A9), UD2.15 (A9), UD7.22 (A9), UE1.15 (A9), UE2.15 (A9); also elsewhere on the board
VA10: U14.19 (A10), U15.19 (A10), UC4.1 (A0), UD7.19 (A10); also elsewhere on the board
VA11: UC4.2 (A1), UD7.18 (A11); also elsewhere on the board
VA12: UC4.3 (A2), UD7.21 (CS2); also elsewhere on the board
VA13: UC4.6 (E3), UD7.20 (~CS1); also elsewhere on the board
VCC: C18.1, C22.1, C23.1, C24.1, C25.1, C26.1, C27.1, C28.1, C46.1, C49.2, R15.2, R29.2, U14.24 (Vcc), U15.24 (Vcc), UC4.16 (VCC), UD1.14 (Vcc), UD2.18 (Vcc), UD7.24 (Vcc), UE1.18 (Vcc), UE2.18 (Vcc), UE11.24 (Vcc), UE12.24 (Vcc); also elsewhere on the board
VD8: UD1.3 (2B), UE1.14 (D0); also elsewhere on the board
VD9: UD1.10 (4B), UE1.13 (D1); also elsewhere on the board
VD10: UD1.2 (1B), UE1.12 (D2); also elsewhere on the board
VD11: UD1.9 (3B), UE1.11 (D3); also elsewhere on the board
VR#W: R29.1, U14.21 (R/~W), U15.21 (R/~W), UD2.10 (R/~W), UE1.10 (R/~W), UE2.10 (R/~W); also elsewhere on the board

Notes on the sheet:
$9600-97FF
4/24/22: Newly-discovered prototype of a VIC20CR had eight 6116 (2kx8) RAM chips in addition to the original three 2114AL (1kx4) chips. This configuration would fill BLK1 (8k) and only part of BLK2 (4K) because two would have been used for the CS_RAM1 and CS_RAM2 blocks above. It would seem that th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
$8000-8FFF
COLOR RAM CONTROL
$0000 $0400 $0800 $0C00
$0000-1FFF
KERNAL ROM
$0400 $0800 $1000
Note: On the prototype, the 2114 data pins are drawn backwards. D0->D3 is 11->14
* When CPU has access VA13 is substituted with BLK4 line.
COLOR RAM
CHR ROM
$C000-DFFF
4/24/22: tied U14/U15 R/W to VR/W
RAM — $1000 - $1FFF
BASIC ROM
$E000-FFFF
$1000-17FF $1800/1FFF
Some schematics show R29 at 470 ohms. Add 890 ohm in parallel to 1k for testing.
RAM — $0000 - $03FF

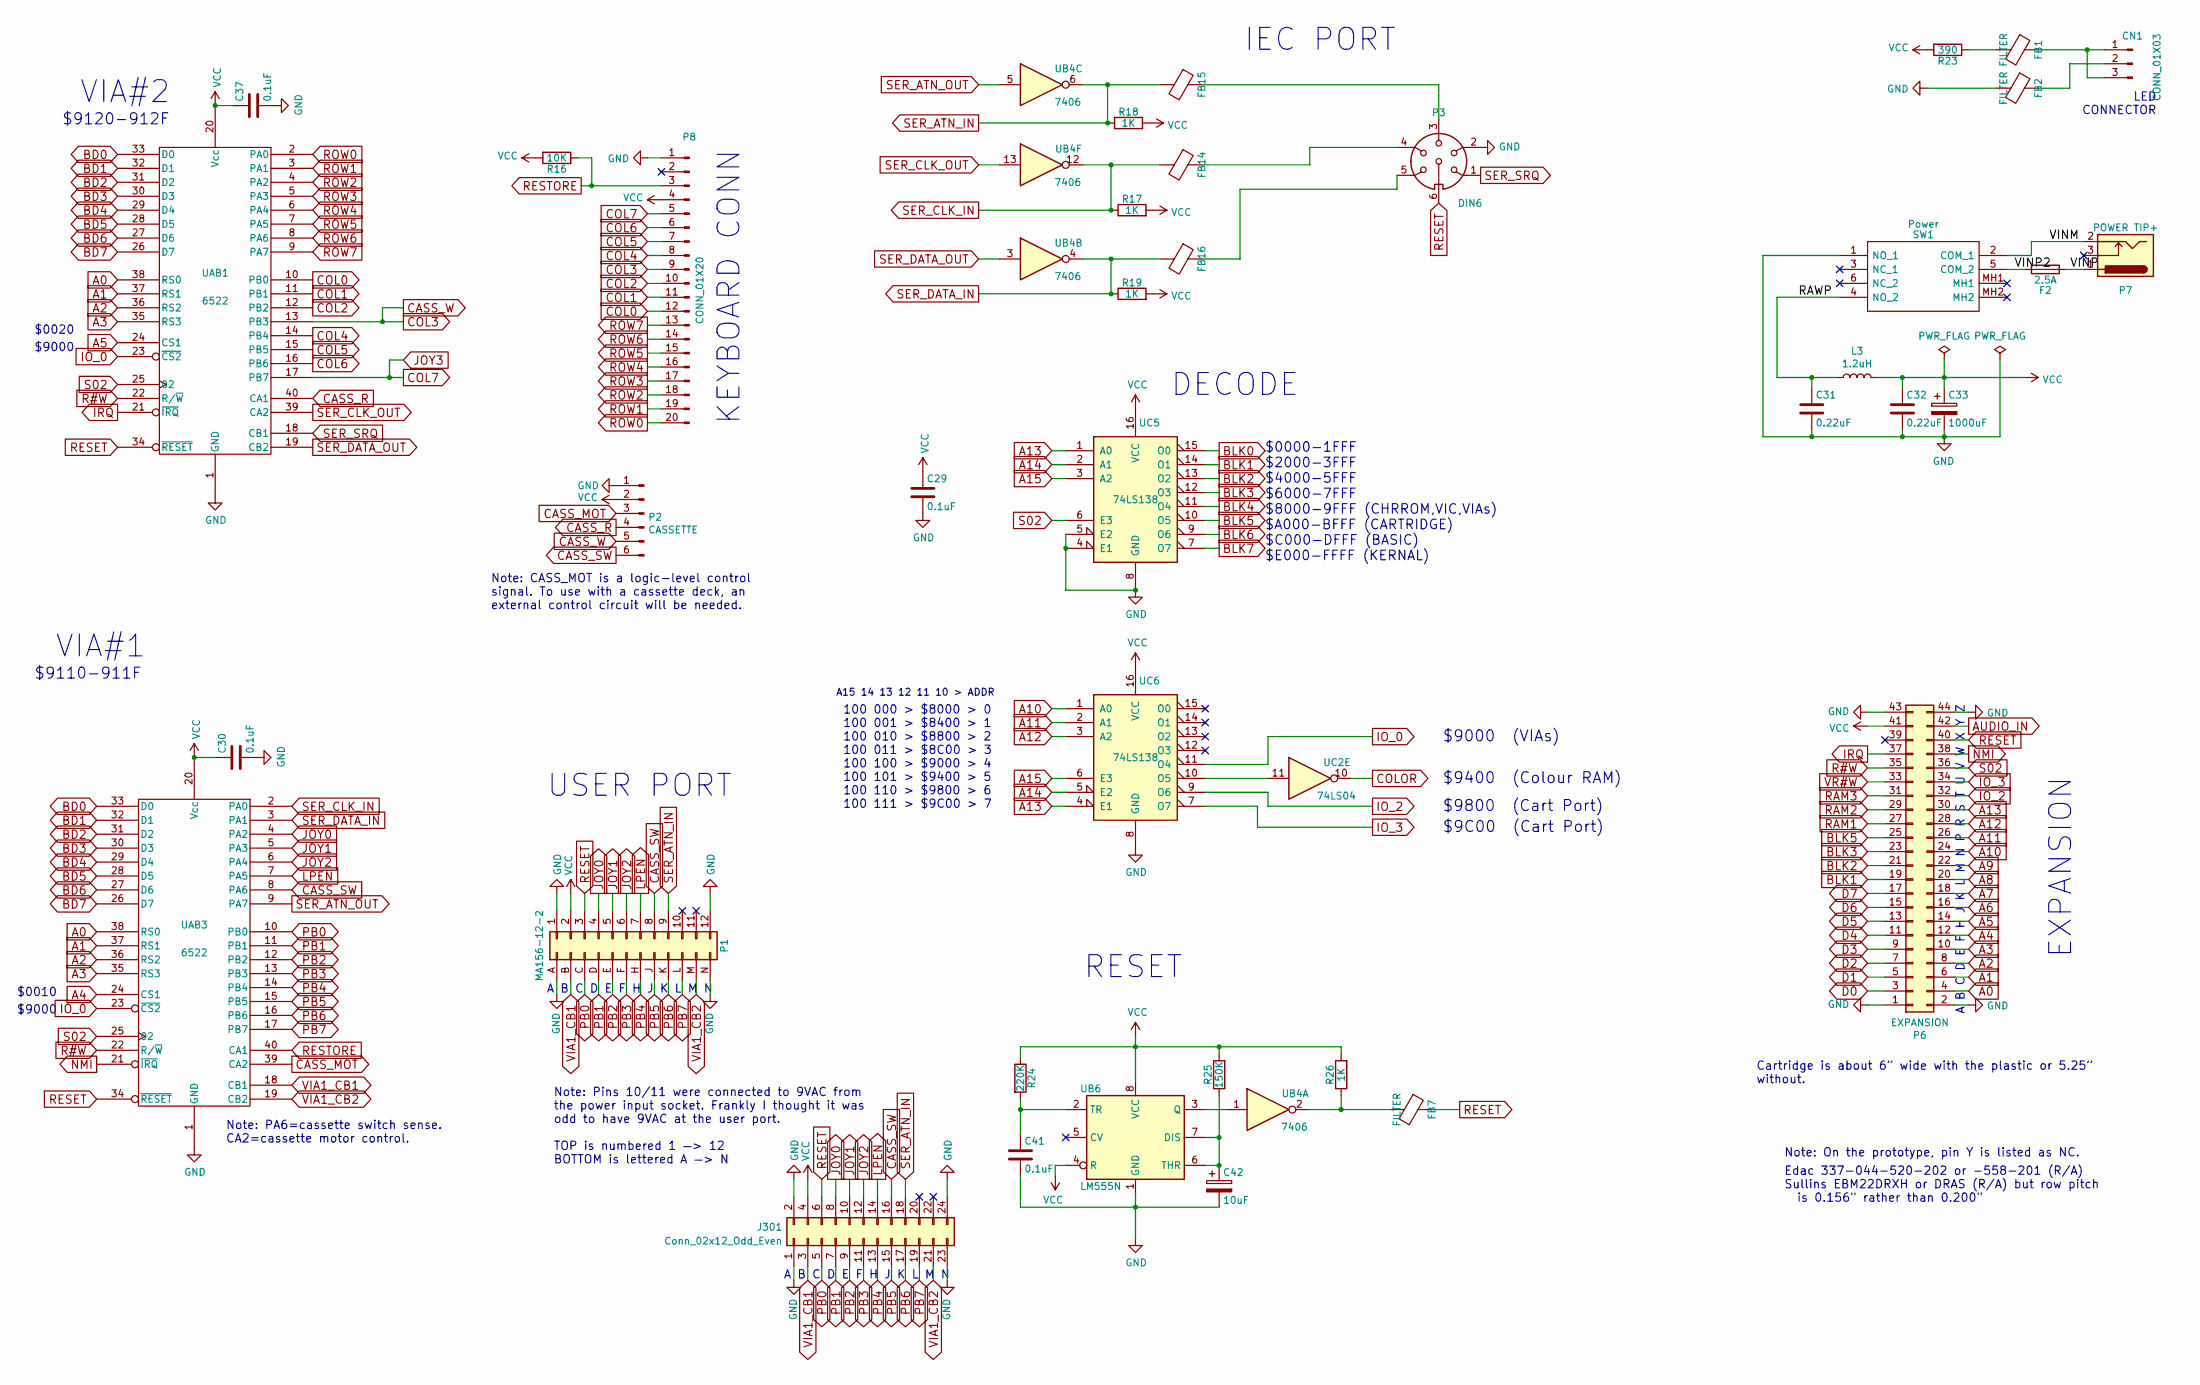
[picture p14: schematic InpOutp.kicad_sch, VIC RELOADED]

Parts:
C29, C30, C37, C41: 0.1uF; C_Disc_D4.3mm_W1.9mm_P5.00mm
C31, C32: 0.22uF; C_Disc_D4.3mm_W1.9mm_P5.00mm
C33: 1000uF; CP_Radial_D10.0mm_P5.00mm
C42: 10uF; CP_Radial_D4.0mm_P1.50mm
CN1: CONN_01X03; PinHeader_1x03_P2.54mm_Vertical
F2: 2.5A; FUSE_4527
FB1, FB2: FILTER; L_Axial_L7.0mm_D3.3mm_P2.54mm_Vertical_Fastron_MICC
FB7, FB14, FB15, FB16: FILTER; L_Axial_L7.0mm_D3.3mm_P10.16mm_Horizontal_Fastron_MICC
J301: Conn_02x12_Odd_Even; PinHeader_2x12_P2.54mm_Vertical
L3: 1.2uH; L_Axial_L7.0mm_D3.3mm_P10.16mm_Horizontal_Fastron_MICC
P1: MA156-12-2
P2: CASSETTE; PinHeader_1x06_P2.54mm_Vertical
P3: DIN6; CUI_SDS-60J
P6: EXPANSION; Sullins_02_22_Card_Edge_Connector
P7: POWER TIP+; BarrelJack_Horizontal
P8: CONN_01X20; PinHeader_1x20_P2.54mm_Vertical
R16: 10K; R_Axial_DIN0207_L6.3mm_D2.5mm_P7.62mm_Horizontal
R17, R18, R19, R26: 1K; R_Axial_DIN0207_L6.3mm_D2.5mm_P7.62mm_Horizontal
R23: 390; R_Axial_DIN0207_L6.3mm_D2.5mm_P7.62mm_Horizontal
R24: 220K; R_Axial_DIN0207_L6.3mm_D2.5mm_P7.62mm_Horizontal
R25: 150K; R_Axial_DIN0207_L6.3mm_D2.5mm_P7.62mm_Horizontal
SW1: Power; M2022TXW41DA
UAB1, UAB3: 6522; DIP-40_W15.24mm_Socket
UB4: 7406; DIP-14_W7.62mm_Socket
UB6: LM555N; DIP-8_W7.62mm_Socket
UC2: 74LS04; DIP-14_W7.62mm_Socket
UC5, UC6: 74LS138; DIP-16_W7.62mm_Socket

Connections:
/Input/Output/RAWP: C31.1, L3.1, SW1.4 (NO_2)
/Input/Output/VINM: P7.2, SW1.2 (COM_1)
/Input/Output/VINP: F2.2, P7.1
/Input/Output/VINP2: F2.1, SW1.5 (COM_2)
A0: P6.4, UAB1.38 (RS0), UAB3.38 (RS0); also elsewhere on the board
A1: P6.6, UAB1.37 (RS1), UAB3.37 (RS1); also elsewhere on the board
A2: P6.8, UAB1.36 (RS2), UAB3.36 (RS2); also elsewhere on the board
A3: P6.10, UAB1.35 (RS3), UAB3.35 (RS3); also elsewhere on the board
A4: P6.12, UAB3.24 (CS1); also elsewhere on the board
A5: P6.14, UAB1.24 (CS1); also elsewhere on the board
A6: P6.16; also elsewhere on the board
A7: P6.18; also elsewhere on the board
A8: P6.20; also elsewhere on the board
A9: P6.22; also elsewhere on the board
A10: P6.24, UC6.1 (A0); also elsewhere on the board
A11: P6.26, UC6.2 (A1); also elsewhere on the board
A12: P6.28, UC6.3 (A2); also elsewhere on the board
A13: P6.30, UC5.1 (A0), UC6.4 (E1); also elsewhere on the board
A14: UC5.2 (A1), UC6.5 (E2); also elsewhere on the board
A15: UC5.3 (A2), UC6.6 (E3); also elsewhere on the board
AUDIO_IN: P6.42; also elsewhere on the board
BD0: UAB1.33 (D0), UAB3.33 (D0); also elsewhere on the board
BD1: UAB1.32 (D1), UAB3.32 (D1); also elsewhere on the board
BD2: UAB1.31 (D2), UAB3.31 (D2); also elsewhere on the board
BD3: UAB1.30 (D3), UAB3.30 (D3); also elsewhere on the board
BD4: UAB1.29 (D4), UAB3.29 (D4); also elsewhere on the board
BD5: UAB1.28 (D5), UAB3.28 (D5); also elsewhere on the board
BD6: UAB1.27 (D6), UAB3.27 (D6); also elsewhere on the board
BD7: UAB1.26 (D7), UAB3.26 (D7); also elsewhere on the board
BLK0: UC5.15 (O0); also elsewhere on the board
BLK1: P6.19, UC5.14 (O1); also elsewhere on the board
BLK2: P6.21, UC5.13 (O2); also elsewhere on the board
BLK3: P6.23, UC5.12 (O3); also elsewhere on the board
BLK4: UC5.11 (O4); also elsewhere on the board
BLK5: P6.25, UC5.10 (O5); also elsewhere on the board
BLK6: UC5.9 (O6); also elsewhere on the board
BLK7: UC5.7 (O7); also elsewhere on the board
CASS_MOT: P2.3, UAB3.39 (CA2)
CASS_R: P2.4, UAB1.40 (CA1)
CASS_SW: J301.16, P1.8, P2.6, UAB3.8 (PA6)
CASS_W: P2.5, P8.9, UAB1.13 (PB3)
COL0: P8.12, UAB1.10 (PB0)
COL1: P8.11, UAB1.11 (PB1)
COL2: P8.10, UAB1.12 (PB2)
COL4: P8.8, UAB1.14 (PB4)
COL5: P8.7, UAB1.15 (PB5)
COL6: P8.6, UAB1.16 (PB6)
COL7: P8.5, UAB1.17 (PB7); also elsewhere on the board
COLOR: UC2.10; also elsewhere on the board
D0: P6.3; also elsewhere on the board
D1: P6.5; also elsewhere on the board
D2: P6.7; also elsewhere on the board
D3: P6.9; also elsewhere on the board
D4: P6.11; also elsewhere on the board
D5: P6.13; also elsewhere on the board
D6: P6.15; also elsewhere on the board
D7: P6.17; also elsewhere on the board
GND: C29.2, C30.2, C31.2, C32.2, C33.2, C37.2, C41.2, C42.2, FB2.2, J301.1, J301.2, J301.23, J301.24, P1.1, P1.12, P1.A, P1.N, P2.1, P3.2, P6.1, P6.2, P6.43, P6.44, P8.1, SW1.1 (NO_1), UAB1.1 (GND), UAB3.1 (GND), UB6.1 (GND), UC5.4 (E1), UC5.5 (E2), UC5.8 (GND), UC6.8 (GND); also elsewhere on the board
IO_0: UAB1.23 (~CS2), UAB3.23 (~CS2), UC6.11 (O4)
IO_2: P6.32, UC6.9 (O6); also elsewhere on the board
IO_3: P6.34, UC6.7 (O7); also elsewhere on the board
IRQ: P6.37, UAB1.21 (~IRQ); also elsewhere on the board
JOY0: J301.8, P1.4, UAB3.4 (PA2); also elsewhere on the board
JOY1: J301.10, P1.5, UAB3.5 (PA3); also elsewhere on the board
JOY2: J301.12, P1.6, UAB3.6 (PA4); also elsewhere on the board
LPEN: J301.14, P1.7, UAB3.7 (PA5); also elsewhere on the board
NMI: P6.38, UAB3.21 (~IRQ); also elsewhere on the board
unnamed: C41.1, R24.2, UB6.2 (TR)
unnamed: C42.1, R25.1, UB6.6 (THR), UB6.7 (DIS)
unnamed: CN1.1, CN1.3, FB1.1
unnamed: CN1.2, FB2.1
unnamed: FB1.2, R23.1
unnamed: FB7.2, R26.1, UB4.2
unnamed: FB14.1, P3.4
unnamed: FB15.1, P3.3
unnamed: FB16.1, P3.5
unnamed: UB4.1, UB6.3 (Q)
unnamed: UC2.11, UC6.10 (O5)
PB0: J301.5, P1.C, UAB3.10 (PB0)
PB1: J301.7, P1.D, UAB3.11 (PB1)
PB2: J301.9, P1.E, UAB3.12 (PB2)
PB3: J301.11, P1.F, UAB3.13 (PB3)
PB4: J301.13, P1.H, UAB3.14 (PB4)
PB5: J301.15, P1.J, UAB3.15 (PB5)
PB6: J301.17, P1.K, UAB3.16 (PB6)
PB7: J301.19, P1.L, UAB3.17 (PB7)
R#W: P6.35, UAB1.22 (R/~W), UAB3.22 (R/~W); also elsewhere on the board
RAM1: P6.27; also elsewhere on the board
RAM2: P6.29; also elsewhere on the board
RAM3: P6.31; also elsewhere on the board
RESET: FB7.1, J301.6, P1.3, P3.6, P6.40, UAB1.34 (~RESET), UAB3.34 (~RESET); also elsewhere on the board
RESTORE: P8.3, R16.1, UAB3.40 (CA1)
ROW0: P8.20, UAB1.2 (PA0)
ROW1: P8.19, UAB1.3 (PA1)
ROW2: P8.18, UAB1.4 (PA2)
ROW3: P8.17, UAB1.5 (PA3)
ROW4: P8.16, UAB1.6 (PA4)
ROW5: P8.15, UAB1.7 (PA5)
ROW6: P8.14, UAB1.8 (PA6)
ROW7: P8.13, UAB1.9 (PA7)
S02: P6.36, UAB1.25 (02), UAB3.25 (02), UC5.6 (E3); also elsewhere on the board
SER_ATN_IN: FB15.2, J301.18, P1.9, R18.1, UB4.6
SER_ATN_OUT: UAB3.9 (PA7), UB4.5
SER_CLK_IN: FB14.2, R17.1, UAB3.2 (PA0), UB4.12
SER_CLK_OUT: UAB1.39 (CA2), UB4.13
SER_DATA_IN: FB16.2, R19.1, UAB3.3 (PA1), UB4.4
SER_DATA_OUT: UAB1.19 (CB2), UB4.3
SER_SRQ: P3.1, UAB1.18 (CB1)
VCC: C29.1, C30.1, C32.1, C33.1, C37.1, J301.4, L3.2, P1.2, P2.2, P6.41, P8.4, R16.2, R17.2, R18.2, R19.2, R23.2, R24.1, R25.2, R26.2, UAB1.20 (Vcc), UAB3.20 (Vcc), UB6.4 (R), UB6.8 (VCC), UC5.16 (VCC), UC6.16 (VCC); also elsewhere on the board
VIA1_CB1: J301.3, P1.B, UAB3.18 (CB1)
VIA1_CB2: J301.21, P1.M, UAB3.19 (CB2)
VR#W: P6.33; also elsewhere on the board

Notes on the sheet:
EXPANSION
Cartridge is about 6” wide with the plastic or 5.25” without.
DECODE
RESET
Note: PA6=cassette switch sense. CA2=cassette motor control.
A B C D E F H J K L M N P R S T U V W X Y Z
A B C D E F H J K L M N
$9000
Note: Pins 10/11 were connected to 9VAC from the power input socket. Frankly I thought it was odd to have 9VAC at the user port. TOP is numbered 1 —> 12 BOTTOM is lettered A —> N
IEC PORT
$9C00 (Cart Port)
$9120-912F
Note: On the prototype, pin Y is listed as NC.
LED CONNECTOR
$9400 (Colour RAM)
$9000 (VIAs)
$9800 (Cart Port)
KEYBOARD CONN
Edac 337-044-520-202 or -558-201 (R/A) Sullins EBM22DRXH or DRAS (R/A) but row pitch is 0.156" rather than 0.200"
$0010
USER PORT
$9110-911F
100 000 > $8000 > 0 100 001 > $8400 > 1 100 010 > $8800 > 2 100 011 > $8C00 > 3 100 100 > $9000 > 4 100 101 > $9400 > 5 100 110 > $9800 > 6 100 111 > $9C00 > 7
A15 14 13 12 11 10 > ADDR
Note: CASS_MOT is a logic-level control signal. To use with a cassette deck, an external control circuit will be needed.
VIA#2
$0020
$0000-1FFF $2000-3FFF $4000-5FFF $6000-7FFF $8000-9FFF (CHRROM,VIC,VIAs) $A000-BFFF (CARTRIDGE) $C000-DFFF (BASIC) $E000-FFFF (KERNAL)
VIA#1

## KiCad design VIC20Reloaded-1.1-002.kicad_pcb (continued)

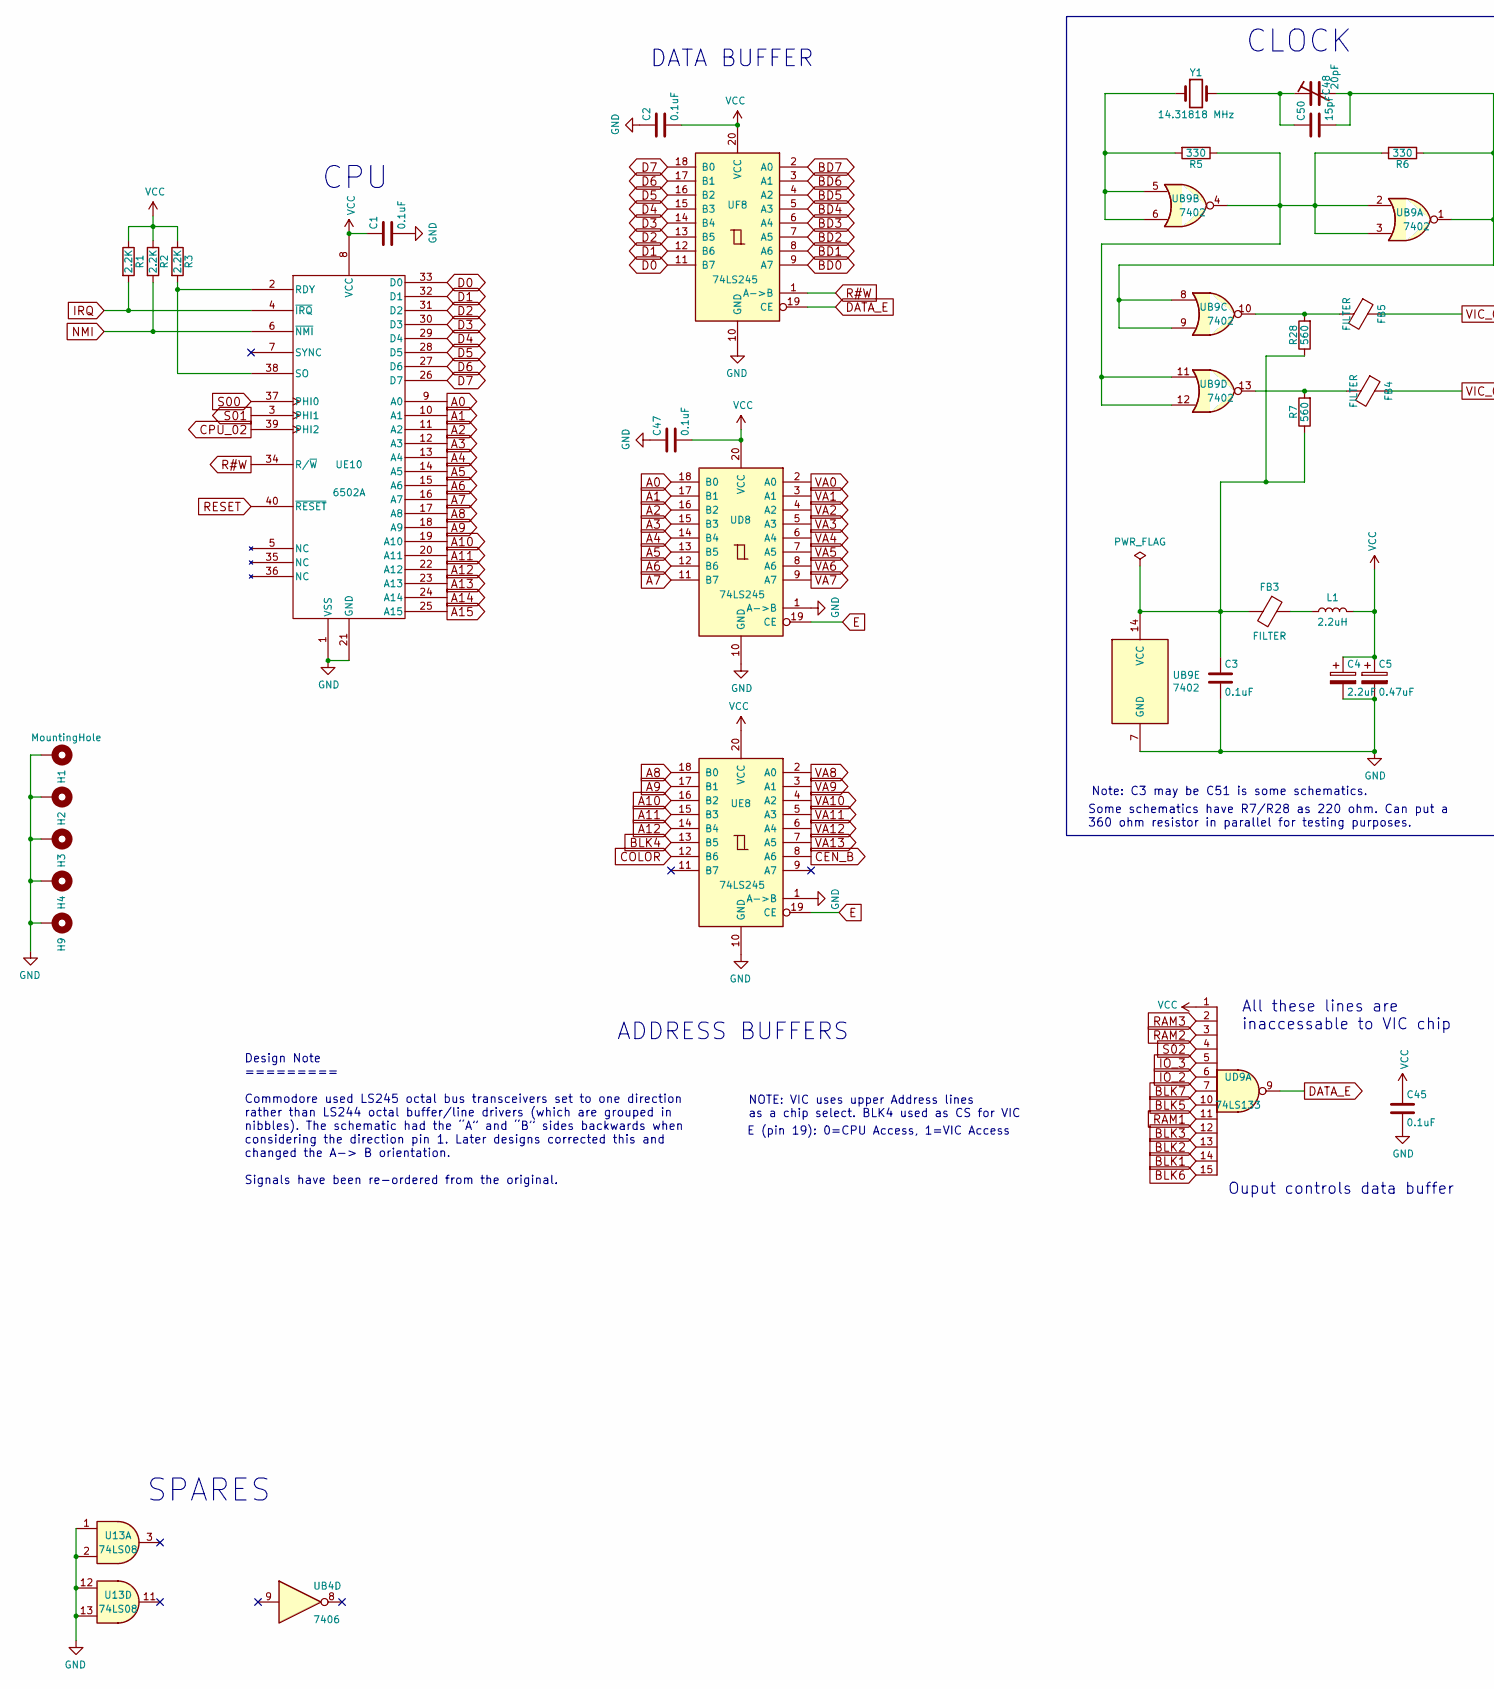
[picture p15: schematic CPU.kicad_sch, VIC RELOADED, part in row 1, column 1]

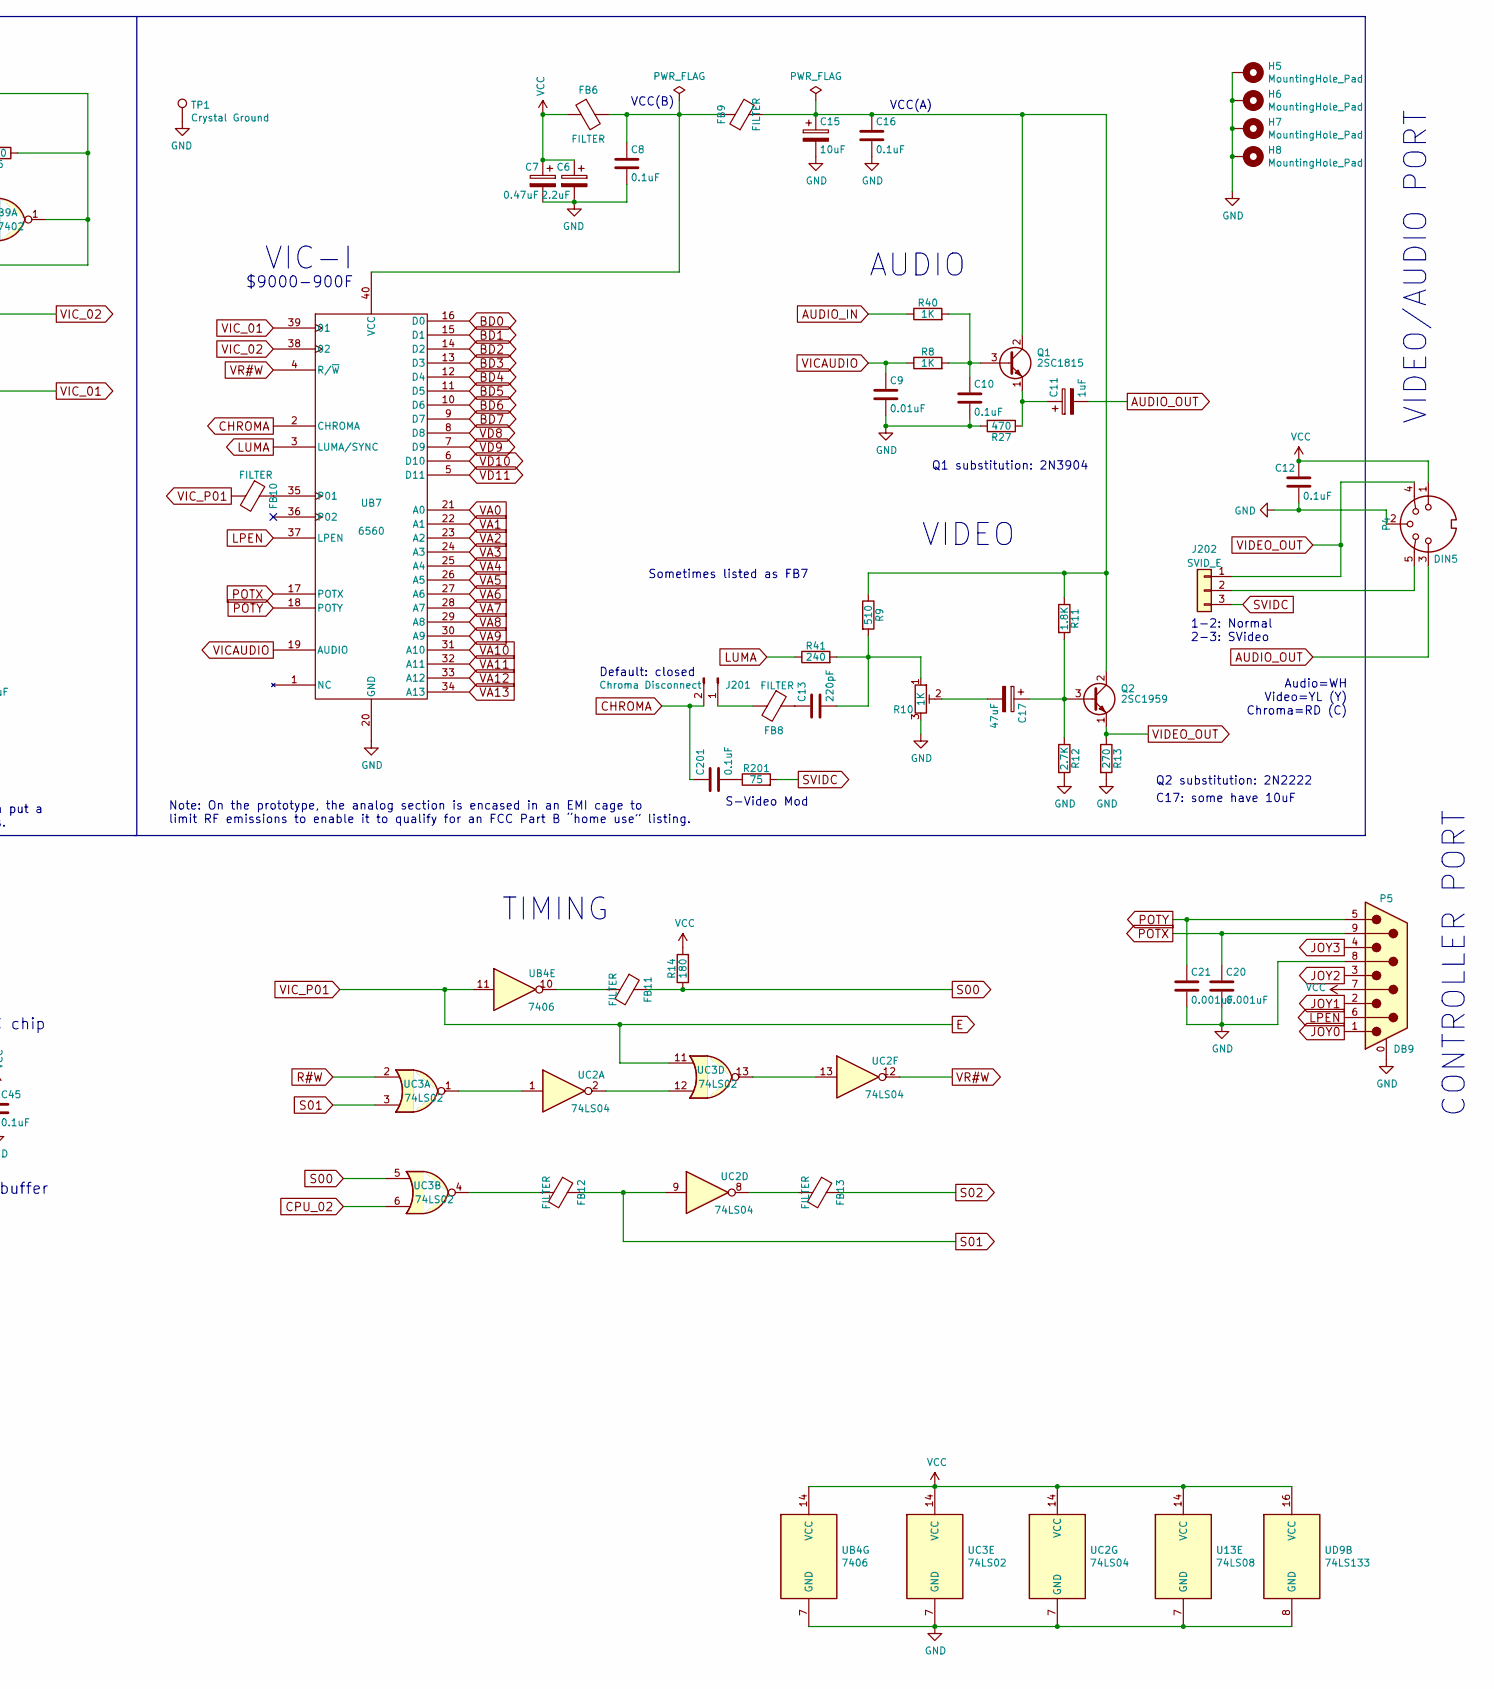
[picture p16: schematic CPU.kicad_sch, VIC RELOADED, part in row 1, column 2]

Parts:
C1, C2, C3, C8, C10, C12, C16, C45, C47, C201: 0.1uF; C_Disc_D4.3mm_W1.9mm_P5.00mm
C4, C6: 2.2uF; CP_Radial_D5.0mm_P2.50mm
C5, C7: 0.47uF; CP_Radial_D5.0mm_P2.50mm
C9: 0.01uF; C_Disc_D4.3mm_W1.9mm_P5.00mm
C11: 1uF; CP_Radial_D4.0mm_P1.50mm
C13: 220pF; C_Disc_D4.3mm_W1.9mm_P5.00mm
C15: 10uF; CP_Radial_D4.0mm_P1.50mm
C17: 47uF; CP_Radial_D5.0mm_P2.00mm
C20, C21: 0.001uF; C_Disc_D4.3mm_W1.9mm_P5.00mm
C48: 20pF; C_Radial_D10.0mm_H12.5mm_P5.00mm
C50: 15pF; C_Disc_D4.3mm_W1.9mm_P5.00mm
FB3, FB6, FB10, FB12, FB13: FILTER; L_Axial_L7.0mm_D3.3mm_P10.16mm_Horizontal_Fastron_MICC
FB4, FB5, FB8, FB9, FB11: FILTER; L_Axial_L7.0mm_D3.3mm_P2.54mm_Vertical_Fastron_MICC
H1, H2, H3, H4, H9: MountingHole; MountingHole_3.2mm_M3_DIN965_Pad
H5, H6, H7, H8: MountingHole_Pad; MountingHole_2.2mm_M2_Pad
J201: Chroma Disconnect; PinHeader_2x01_P2.54mm_Vertical
J202: SVID_E; PinHeader_1x03_P2.54mm_Vertical
L1: 2.2uH; L_Axial_L7.0mm_D3.3mm_P10.16mm_Horizontal_Fastron_MICC
P4: DIN5; CUI_SDS-50J
P5: DB9; DSUB-9_Male_Horizontal_P2.77x2.84mm_EdgePinOffset7.70mm_Hou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
Q1: 2SC1815; TO-92
Q2: 2SC1959; TO-92
R1, R2, R3: 2.2K; R_Axial_DIN0207_L6.3mm_D2.5mm_P7.62mm_Horizontal
R5, R6: 330; R_Axial_DIN0207_L6.3mm_D2.5mm_P2.54mm_Vertical
R7, R28: 560; R_Axial_DIN0207_L6.3mm_D2.5mm_P2.54mm_Vertical
R8, R40: 1K; R_Axial_DIN0207_L6.3mm_D2.5mm_P2.54mm_Vertical
R9: 510; R_Axial_DIN0207_L6.3mm_D2.5mm_P2.54mm_Vertical
R10: 1K; Potentiometer_Bourns_3266W_Vertical
R11: 1.8K; R_Axial_DIN0207_L6.3mm_D2.5mm_P2.54mm_Vertical
R12: 2.7K; R_Axial_DIN0207_L6.3mm_D2.5mm_P2.54mm_Vertical
R13: 270; R_Axial_DIN0207_L6.3mm_D2.5mm_P2.54mm_Vertical
R14: 180; R_Axial_DIN0207_L6.3mm_D2.5mm_P7.62mm_Horizontal
R27: 470; R_Axial_DIN0207_L6.3mm_D2.5mm_P2.54mm_Vertical
R41: 240; R_Axial_DIN0207_L6.3mm_D2.5mm_P2.54mm_Vertical
R201: 75; R_Axial_DIN0207_L6.3mm_D2.5mm_P2.54mm_Vertical
TP1: Crystal Ground; TestPoint_THTPad_D1.0mm_Drill0.5mm
U13: 74LS08; DIP-14_W7.62mm_Socket
UB4: 7406; DIP-14_W7.62mm_Socket
UB7: 6560; DIP-40_W15.24mm_Socket
UB9: 7402; DIP-14_W7.62mm_Socket
UC2: 74LS04; DIP-14_W7.62mm_Socket
UC3: 74LS02; DIP-14_W7.62mm_Socket
UD8: 74LS245; DIP-20_W7.62mm_Socket
UD9: 74LS133; DIP-16_W7.62mm_Socket
UE8: 74LS245; DIP-20_W7.62mm_Socket
UE10: 6502A; DIP-40_W15.24mm_Socket
UF8: 74LS245; DIP-20_W7.62mm_Socket
Y1: 14.31818 MHz; Crystal_HC18-U_Vertical

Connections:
A0: UD8.18 (B0), UE10.9 (A0); also elsewhere on the board
A1: UD8.17 (B1), UE10.10 (A1); also elsewhere on the board
A2: UD8.16 (B2), UE10.11 (A2); also elsewhere on the board
A3: UD8.15 (B3), UE10.12 (A3); also elsewhere on the board
A4: UD8.14 (B4), UE10.13 (A4); also elsewhere on the board
A5: UD8.13 (B5), UE10.14 (A5); also elsewhere on the board
A6: UD8.12 (B6), UE10.15 (A6); also elsewhere on the board
A7: UD8.11 (B7), UE10.16 (A7); also elsewhere on the board
A8: UE8.18 (B0), UE10.17 (A8); also elsewhere on the board
A9: UE8.17 (B1), UE10.18 (A9); also elsewhere on the board
A10: UE8.16 (B2), UE10.19 (A10); also elsewhere on the board
A11: UE8.15 (B3), UE10.20 (A11); also elsewhere on the board
A12: UE8.14 (B4), UE10.22 (A12); also elsewhere on the board
A13: UE10.23 (A13); also elsewhere on the board
A14: UE10.24 (A14); also elsewhere on the board
A15: UE10.25 (A15); also elsewhere on the board
AUDIO_IN: R40.1; also elsewhere on the board
AUDIO_OUT: C11.2, P4.3
BD0: UB7.16 (D0), UF8.9 (A7); also elsewhere on the board
BD1: UB7.15 (D1), UF8.8 (A6); also elsewhere on the board
BD2: UB7.14 (D2), UF8.7 (A5); also elsewhere on the board
BD3: UB7.13 (D3), UF8.6 (A4); also elsewhere on the board
BD4: UB7.12 (D4), UF8.5 (A3); also elsewhere on the board
BD5: UB7.11 (D5), UF8.4 (A2); also elsewhere on the board
BD6: UB7.10 (D6), UF8.3 (A1); also elsewhere on the board
BD7: UB7.9 (D7), UF8.2 (A0); also elsewhere on the board
BLK1: UD9.14; also elsewhere on the board
BLK2: UD9.13; also elsewhere on the board
BLK3: UD9.12; also elsewhere on the board
BLK4: UE8.13 (B5); also elsewhere on the board
BLK5: UD9.10; also elsewhere on the board
BLK6: UD9.15; also elsewhere on the board
BLK7: UD9.7; also elsewhere on the board
CEN_B: UE8.8 (A6); also elsewhere on the board
CHROMA: C201.1, J201.2, UB7.2 (CHROMA)
COL7: P5.4; also elsewhere on the board
COLOR: UE8.12 (B6); also elsewhere on the board
CPU_02: UC3.6, UE10.39 (PHI2)
D0: UE10.33 (D0), UF8.11 (B7); also elsewhere on the board
D1: UE10.32 (D1), UF8.12 (B6); also elsewhere on the board
D2: UE10.31 (D2), UF8.13 (B5); also elsewhere on the board
D3: UE10.30 (D3), UF8.14 (B4); also elsewhere on the board
D4: UE10.29 (D4), UF8.15 (B3); also elsewhere on the board
D5: UE10.28 (D5), UF8.16 (B2); also elsewhere on the board
D6: UE10.27 (D6), UF8.17 (B1); also elsewhere on the board
D7: UE10.26 (D7), UF8.18 (B0); also elsewhere on the board
DATA_E: UD9.9, UF8.19 (CE)
E: FB10.2, UB4.11, UC3.11, UD8.19 (CE), UE8.19 (CE)
GND: C1.2, C2.1, C3.2, C4.2, C5.2, C6.2, C7.2, C8.2, C9.2, C10.2, C12.2, C15.2, C16.2, C20.2, C21.2, C45.2, C47.1, H1.1, H2.1, H3.1, H4.1, H5.1, H6.1, H7.1, H8.1, H9.1, P4.2, P5.0 (PAD), P5.8, R10.3, R12.2, R13.2, R27.2, TP1.1, U13.1, U13.2, U13.7 (GND), U13.12, U13.13, UB4.7 (GND), UB7.20 (GND), UB9.7 (GND), UC2.7 (GND), UC3.7 (GND), UD8.1 (A->B), UD8.10 (GND), UD9.8 (GND), UE8.1 (A->B), UE8.10 (GND), UE10.1 (VSS), UE10.21 (GND), UF8.10 (GND); also elsewhere on the board
IO_2: UD9.6; also elsewhere on the board
IO_3: UD9.5; also elsewhere on the board
IRQ: R1.2, UE10.4 (~IRQ); also elsewhere on the board
JOY0: P5.1; also elsewhere on the board
JOY1: P5.2; also elsewhere on the board
JOY2: P5.3; also elsewhere on the board
LPEN: P5.6, UB7.37 (LPEN); also elsewhere on the board
LUMA: R41.1, UB7.3 (LUMA/SYNC)
NMI: R2.2, UE10.6 (~NMI); also elsewhere on the board
unnamed: C3.1, FB3.2, R7.1, R28.1, UB9.14 (VCC)
unnamed: C8.1, FB6.2, FB9.1, UB7.40 (VCC)
unnamed: C10.1, Q1.3 (B), R8.2, R40.2
unnamed: C11.1, Q1.1 (E), R27.1
unnamed: C13.1, FB8.1
unnamed: C13.2, R9.2, R10.1, R41.2
unnamed: C15.1, C16.1, FB9.2, Q1.2 (C), Q2.2 (C), R9.1, R11.1
unnamed: C17.1, Q2.3 (B), R11.2, R12.1
unnamed: C17.2, R10.2
unnamed: C48.1, C50.1, Y1.2
unnamed: C48.2, C50.2, R6.1, UB9.1, UB9.8, UB9.9
unnamed: C201.2, R201.1
unnamed: FB3.1, L1.1
unnamed: FB4.2, R7.2, UB9.13
unnamed: FB5.2, R28.2, UB9.10
unnamed: FB8.2, J201.1
unnamed: FB10.1, UB7.35 (P01)
unnamed: FB11.2, UB4.10
unnamed: FB12.2, UC3.4
unnamed: FB13.2, UC2.8
unnamed: J202.2, P4.5
unnamed: R3.2, UE10.2 (RDY), UE10.38 (SO)
unnamed: R5.1, R6.2, UB9.2, UB9.3, UB9.4, UB9.11, UB9.12
unnamed: R5.2, UB9.5, UB9.6, Y1.1
unnamed: UC2.1, UC3.1
unnamed: UC2.2, UC3.12
unnamed: UC2.13, UC3.13
POTX: C20.1, P5.9, UB7.17 (POTX)
POTY: C21.1, P5.5, UB7.18 (POTY)
R#W: UC3.2, UE10.34 (R/~W), UF8.1 (A->B); also elsewhere on the board
RAM1: UD9.11; also elsewhere on the board
RAM2: UD9.3; also elsewhere on the board
RAM3: UD9.2; also elsewhere on the board
RESET: UE10.40 (~RESET); also elsewhere on the board
S00: FB11.1, R14.1, UC3.5, UE10.37 (PHI0)
S01: FB12.1, UC2.9, UC3.3, UE10.3 (PHI1); also elsewhere on the board
S02: FB13.1, UD9.4; also elsewhere on the board
SVIDC: J202.3, R201.2
VA0: UB7.21 (A0), UD8.2 (A0); also elsewhere on the board
VA1: UB7.22 (A1), UD8.3 (A1); also elsewhere on the board
VA2: UB7.23 (A2), UD8.4 (A2); also elsewhere on the board
VA3: UB7.24 (A3), UD8.5 (A3); also elsewhere on the board
VA4: UB7.25 (A4), UD8.6 (A4); also elsewhere on the board
VA5: UB7.26 (A5), UD8.7 (A5); also elsewhere on the board
VA6: UB7.27 (A6), UD8.8 (A6); also elsewhere on the board
VA7: UB7.28 (A7), UD8.9 (A7); also elsewhere on the board
VA8: UB7.29 (A8), UE8.2 (A0); also elsewhere on the board
VA9: UB7.30 (A9), UE8.3 (A1); also elsewhere on the board
VA10: UB7.31 (A10), UE8.4 (A2); also elsewhere on the board
VA11: UB7.32 (A11), UE8.5 (A3); also elsewhere on the board
VA12: UB7.33 (A12), UE8.6 (A4); also elsewhere on the board
VA13: UB7.34 (A13), UE8.7 (A5); also elsewhere on the board
VCC: C1.1, C2.2, C4.1, C5.1, C6.1, C7.1, C12.1, C45.1, C47.2, FB6.1, L1.2, P4.1, P5.7, R1.1, R2.1, R3.1, R14.2, U13.14 (VCC), UB4.14 (VCC), UC2.14 (VCC), UC3.14 (VCC), UD8.20 (VCC), UD9.1, UD9.16 (VCC), UE8.20 (VCC), UE10.8 (VCC), UF8.20 (VCC); also elsewhere on the board
VD8: UB7.8 (D8); also elsewhere on the board
VD9: UB7.7 (D9); also elsewhere on the board
VD10: UB7.6 (D10); also elsewhere on the board
VD11: UB7.5 (D11); also elsewhere on the board
VICAUDIO: C9.1, R8.1, UB7.19 (AUDIO)
VIC_01: FB4.1, UB7.39 (01)
VIC_02: FB5.1, UB7.38 (02)
VIDEO_OUT: J202.1, P4.4, Q2.1 (E), R13.1
VR#W: UB7.4 (R/~W), UC2.12; also elsewhere on the board

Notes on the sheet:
CLOCK
$9000-900F
TIMING
VCC(B)
Default: closed
CPU
Ouput controls data buffer
Note: C3 may be C51 is some schematics.
VIC-I
SPARES
VIDEO
VCC(A)
NOTE: VIC uses upper Address lines as a chip select. BLK4 used as CS for VIC
1-2: Normal 2-3: SVideo
AUDIO
Sometimes listed as FB7
Q1 substitution: 2N3904
ADDRESS BUFFERS
E (pin 19): 0=CPU Access, 1=VIC Access
DATA BUFFER
All these lines are inaccessable to VIC chip
C17: some have 10uF
Q2 substitution: 2N2222
S-Video Mod
VIDEO/AUDIO PORT
Audio=WH Video=YL (Y) Chroma=RD (C)
Note: On the prototype, the analog section is encased in an EMI cage to limit RF emissions to enable it to qualify for an FCC Part B “home use” listing.
Design Note ========= Commodore used LS245 octal bus transceivers set to one direction rather than LS244 octal buffer/line drivers (which are grouped in nibbles). The schematic had the “A” and “B” sides backwards when considering the direction pin 1. Later designs corrected this and changed the A->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
Some schematics have R7/R28 as 220 ohm. Can put a 360 ohm resistor in parallel for testing purposes.
CONTROLLER PORT

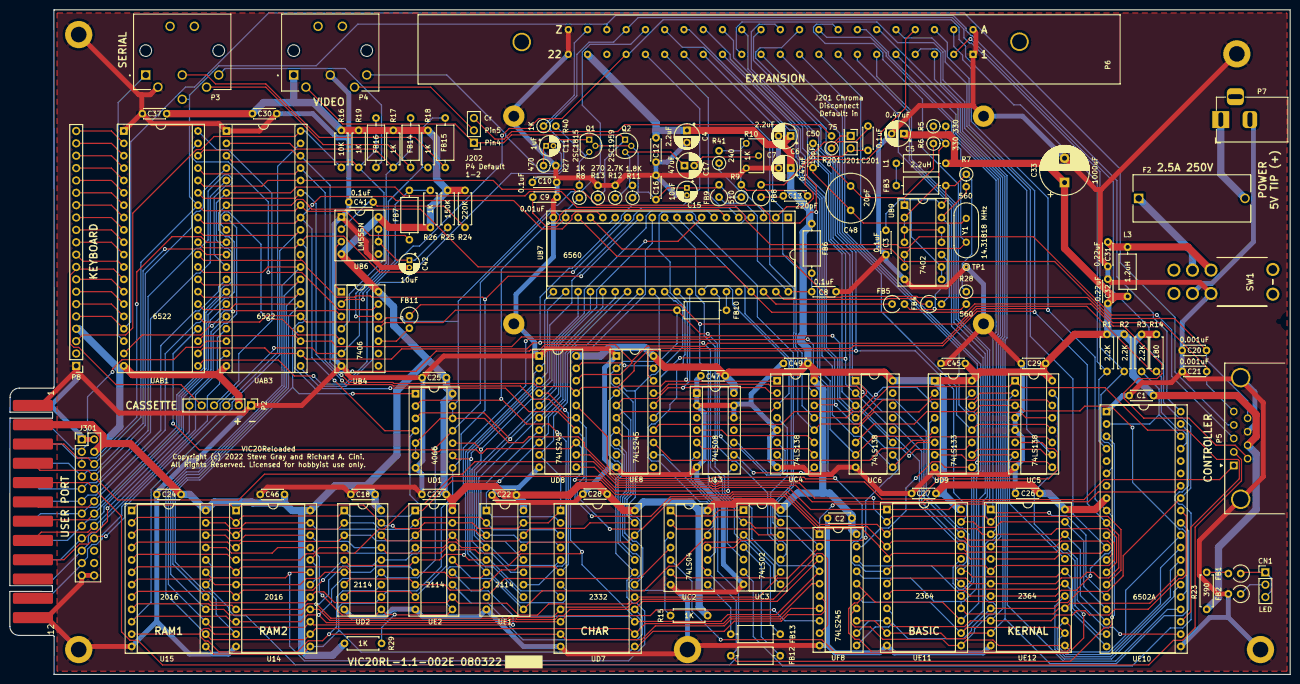
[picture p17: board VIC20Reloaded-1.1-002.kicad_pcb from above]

Board: 2 copper layers, 263.1 x 136.6 mm, 140 parts (1 on the bottom side), 183 nets.

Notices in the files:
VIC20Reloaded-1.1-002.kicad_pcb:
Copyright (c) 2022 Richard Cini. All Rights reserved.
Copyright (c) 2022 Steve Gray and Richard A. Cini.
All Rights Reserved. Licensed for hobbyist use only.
